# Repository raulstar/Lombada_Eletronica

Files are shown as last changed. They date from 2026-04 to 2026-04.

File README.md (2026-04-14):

#  Lombada Eletrônica - Sistema de Detecção de Velocidade com Visão Computacional

##  Descrição do Projeto
Este projeto tem como objetivo desenvolver um sistema capaz de rastrear, identificar e registrar a velocidade de veículos, além de capturar imagens, utilizando visão computacional com OpenCV em Python 3.

Na primeira versão o sistema opera em um computador embarcado, utilizando uma câmera de vídeo para monitoramento contínuo do tráfego.
Na segunda versão Usam um sensor de radar niko-ondas Para ler A velocidade.

---

##  Objetivo
Desenvolver um programa que:
- Detecte veículos em vídeo
- Rastreie cada veículo com ID único
- Calcule a velocidade com base no método VASCAR
- Registre dados e imagens dos veículos
- Identifique infrações de velocidade

---

##  Requisitos do Sistema

###  Hardware
- Gabinete metálico
– Estrutura metalica
- Banco de bateria
- A placa solar
- Mini PC x64
- Mínimo:
  - 4 GB RAM
  - Processador Intel Celeron N4120
- Compatível com:
  - Windows 10 / Windows 11 (23H2)
  - (Opcional) Raspberry Pi OS (Debian)
  - Câmera de CFTV

---

### Software
- Python 3
- OpenCV
- Adu

---

## Arquitetura de Referência
Protótipo base:
https://github.com/raulstar/Software_Lombada

---

## Funcionalidades

### Entrada de Vídeo
- Captura via:
  - Arquivo de vídeo
  - Câmera embarcada
- Suporte a resoluções:
  - 1280x720
  - 1920x1080
- FPS configurável ou automático

---

### Detecção e Rastreamento
- Identificação de veículos em diferentes:
  - Ângulos
  - Elevações
  - Sentidos de tráfego
- Atribuição de ID único por veículo
- Caixa de detecção (bounding box)
- Região de interesse (ROI) configurável

---

### Cálculo de Velocidade
- Baseado no método VASCAR
- Linhas de início/fim configuráveis
- Exibição em tempo real:
  - ID
  - Velocidade

---

### Controle de Velocidade
- Definição de limite de velocidade
- Identificação de veículos infratores

---

### 🧾 Registro de Dados (LOG)

ID   VELOCIDADE   DATA/HORA
--------------------------------------------------
1    20.66 KM/h   2025-01-21 09:16:21  <--- excedeu limite
4    29.94 KM/h   2025-01-21 09:16:26  <--- excedeu limite
7    35.99 KM/h   2025-01-21 09:16:55  <--- excedeu limite

---

###  Captura de Imagens
- Registro automático de veículos infratores
- Foco na placa
- Imagens com qualidade suficiente para OCR futuro

---

### Comunicação Serial
- Detecção automática de portas seriais
- Envio de dados via:

serial.Serial("COMX", 9600, timeout=0.5)

- Formato ASCII com velocidade excedida

---

### Dependências
Deve incluir:
- Lista completa de bibliotecas
- Versões utilizadas
- Código-fonte completo

---

## Testes Realizados
- Resoluções testadas:
  - 1280x720
  - 1920x1080

---

##  Limitações do Protótipo Atual
- Baixa precisão na detecção
- Identificação incorreta de partes de veículos
- Velocidades inconsistentes
- Perda de veículos reais
- Múltiplos registros para o mesmo veículo

---

##  Problemas Observados
- Captura de objetos errados (ex: vidro do carro)
- Falha em detectar veículos grandes (ex: caminhões)
- Poucas imagens com foco correto na placa
- Associação incorreta entre ID e imagem

---

##  Requisitos Esperados
- Um único registro por veículo
- Associação correta entre:
  - ID
  - Imagem
  - Velocidade
- Geração de miniatura por registro com uma ID

---

##  Futuras Etapas
- Migração para nuvem
- Interface web (browser)
- Controle de acesso
- Suporte a múltiplas câmeras
- Integração com OCR (leitura de placas)
- Registro e consulta de todos os dados capturados
- O uso do Radar de microondas

---

##  Protótipo
O protótipo atual já implementa grande parte das funcionalidades, porém ainda com limitações de precisão:

https://github.com/raulstar/Software_Lombada

---

##  Imagens

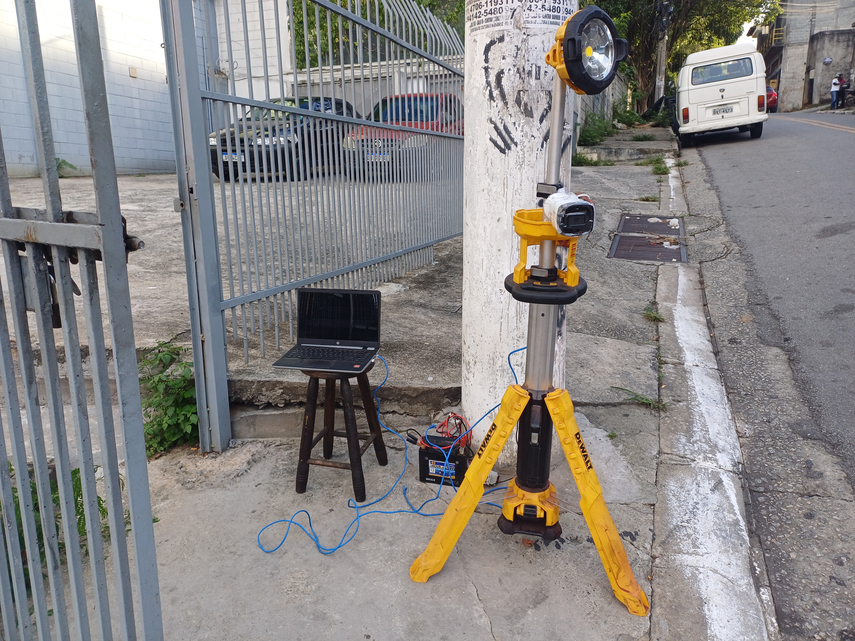
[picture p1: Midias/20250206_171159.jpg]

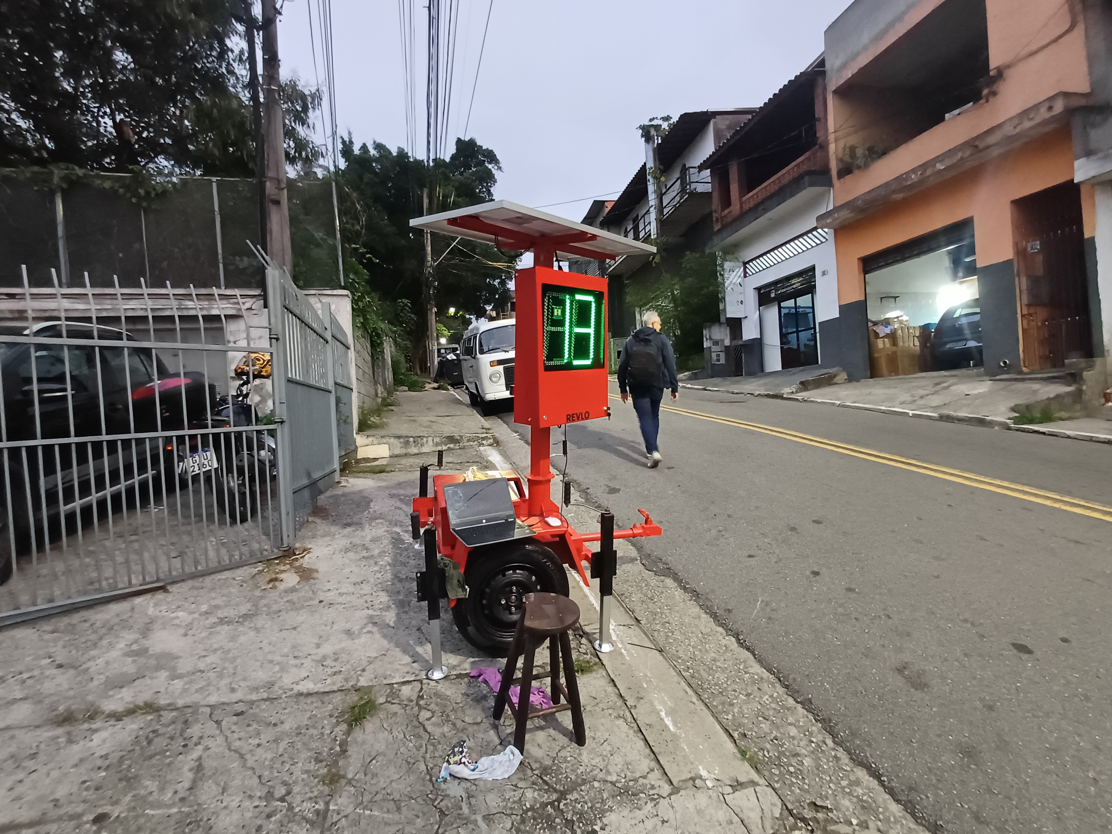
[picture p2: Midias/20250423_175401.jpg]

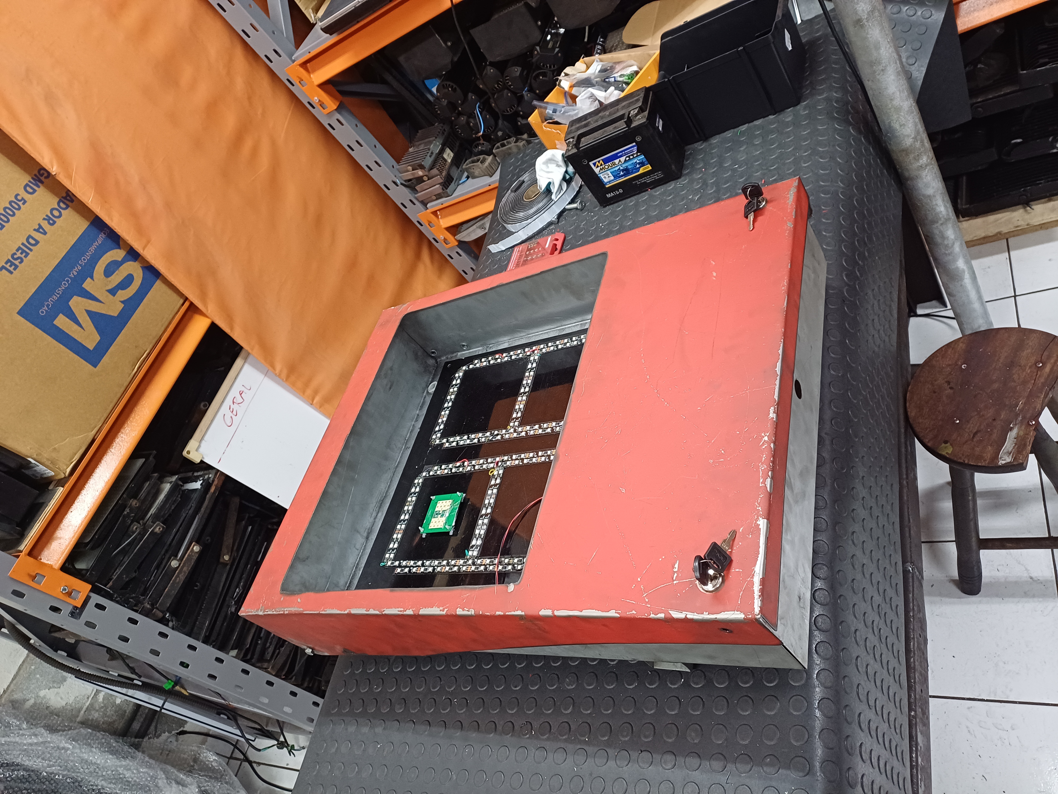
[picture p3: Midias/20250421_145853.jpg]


---

##  Vídeos

[Video 1](Midias/20250423_180011.mp4)
[Video 2](Midias/Primeiro teste (2).mp4)

---

##  Observação Final
Apesar das limitações, o protótipo demonstrou viabilidade ao:
- Detectar veículos corretamente em diversos cenários
- Capturar imagens com enquadramento adequado da placa
O pretóxico Radar Foi usado diversas vezes inclusive um dado para clientes Mas o projeto está alto pausado no Momento.
O próximo passo ser A captura das irmãs com a Câmera e o enviou para um servidor via MQTT.

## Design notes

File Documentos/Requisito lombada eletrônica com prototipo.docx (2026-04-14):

Requisitos do Projeto: Lombada Eletrônica

Objetivo:
Desenvolver um programa que rastreie, identifique e registre a velocidade e imagens de veículos utilizando uma câmera de vídeo, operando em um computador embarcado.

Primeira Etapa

Desenvolvimento de um programa em Python 3, baseado na biblioteca OpenCV, que deve rodar em:

Mini PC x64 com as seguintes especificações mínimas de 4 GB de RAM, Processador Celeron N4120, Compatível com Windows 10 ou Windows 11 23H2. Opcionalmente: Suporte ao sistema operacional Raspberry Pi OS (Debian).

Referência de arquitetura:
O protótipo pode seguir como base o exemplo disponível em:
https://github.com/raulstar/Software_Lombada

Requisitos do Programa:

- O cálculo da velocidade deve ser baseado no conceito VASCAR (saiba mais (https://en.wikipedia.org/wiki/VASCAR)).
- Deve permitir a definição da velocidade máxima por interface ou variável.
- O programa deve oferecer suporte à captura de vídeo por arquivo ou câmera embarcada.
- É necessário processar vídeos em resoluções de 1280 x 720 e 1920 x 1080, ajustáveis por variável ou detectadas automaticamente.
- Deve suportar diferentes taxas de quadros, configuráveis por variável ou por detecção automática.
- O sistema deve rastrear e registrar veículos em diferentes ângulos, elevações, sentidos de tráfego e configurações de câmeras
- Deve permitir a definição de uma região de interesse (ROI), opcionalmente ajustável por variáveis. configuráveis por variável ou por detecção automática
- Ter como opcional o desenho de linhas de início e fim para detecção de velocidade e o desenho de uma caixa ao redor dos objetos rastreados. Cada objeto deve receber um ID único.
- O programa deve estimar a velocidade dos veículos, exibindo o ID e a velocidade junto à caixa de rastreamento.
- Deve ser possível registrar os dados em um arquivo de log, incluindo a quantidade total de veículos detectados, a velocidade de cada veículo e a identificação daqueles que ultrapassaram o limite de velocidade. Além disso, o sistema deve capturar imagens dos veículos que excederem o limite, com foco na placa.
- O programa deve realizar a varredura e identificação das portas seriais disponíveis no dispositivo, enviando a velocidade excedida no formato string ASCII para a porta serial disponível no seguinte formato: serial.Serial("COMX", 9600, timeout=0.5).
- É necessário fornecer a relação completa das bibliotecas, dependências e versões utilizadas no programa, bem como incluir todo o código-fonte no projeto.

Exemplo de Testes

Exemplo testes realizados com um programa protótipo. Resoluções testadas: 1280 x 720 e 1920 x 1080.

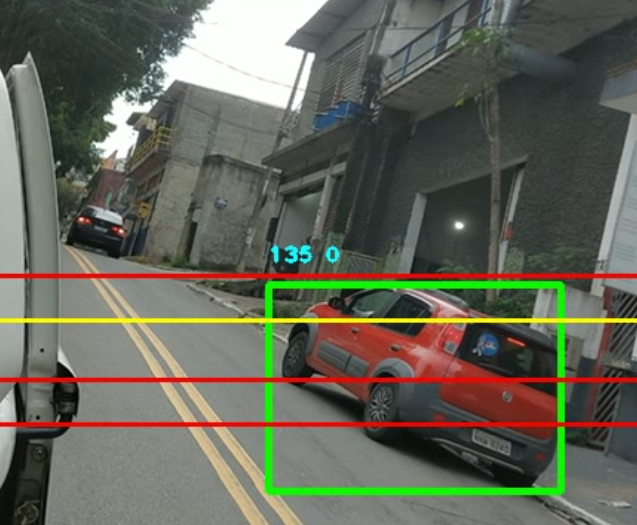
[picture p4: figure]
Teste do prototipo
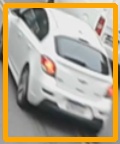
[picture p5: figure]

O As imagens capturadas e registradas deve garantir legibilidade suficiente nas imagens capturadas para integração futura com um programa de OCR.

Futuras Etapas

Com base nos resultados desta primeira etapa, a próxima fase incluirá a migração do programa para a nuvem, com interface acessível via navegador, gerenciamento de acesso, ajuste das variáveis, suporte a diversas câmeras, reconhecimento óptico das placas, registro e consulta de todos os dados capturados.

Protótipo

Foi feito um protótipo para testar a viabilidade do projeto já com a maior parte das funcionalidades funcionais embora a precisão ainda é muito baixa e detecta erroneamente os veículos atribuindo velocidades inconsistentes esse projeto está disponível em: https://github.com/raulstar/Software_Lombada

O exemplo abaixo foi capturado com uma Câmera HD com resolução de 1920 x 1080 em uma rua em frente à nossa sede nesse exemplo tem 3 veículos, mas esse protótipo capturou Falsamente o vidro de um carro e ignorou a frente do caminhão.

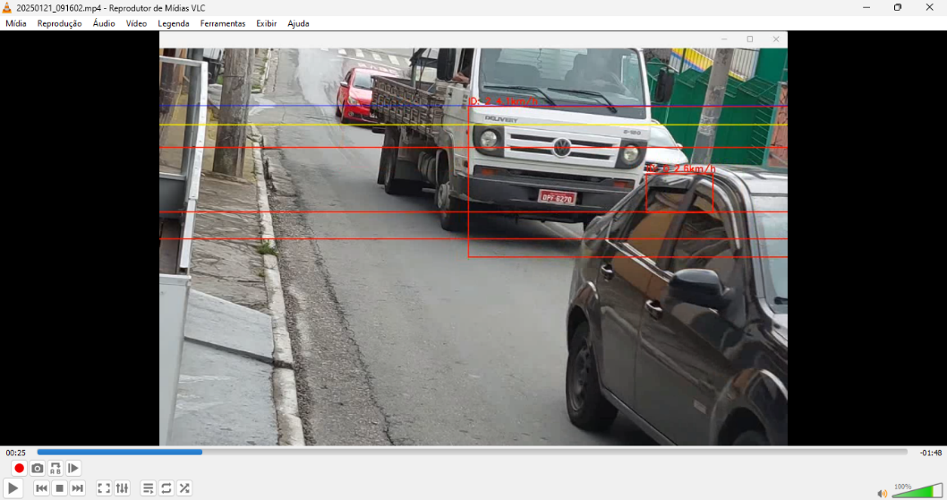
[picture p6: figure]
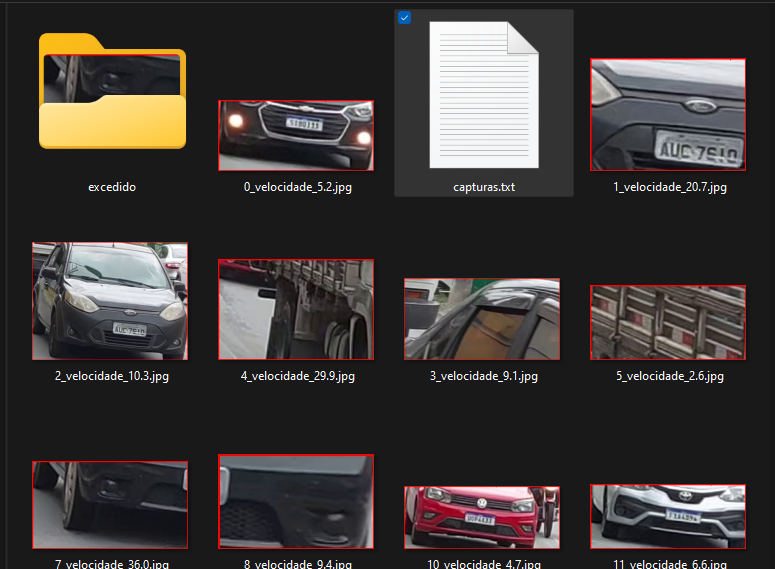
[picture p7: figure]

O protótipo também salva as imagens capturadas do veículo nesse vídeo, com 6 veículos passando foro capturado apenas 3 veículos diferentes sendo que pouca dessas imagens foro capturada apenas à frente com a placa.

Apesar do protótipo conseguir capturar a maioria dos veículos também captura parte, atribuindo uma ideia e uma velocidade errônea ao mesmo veículo.

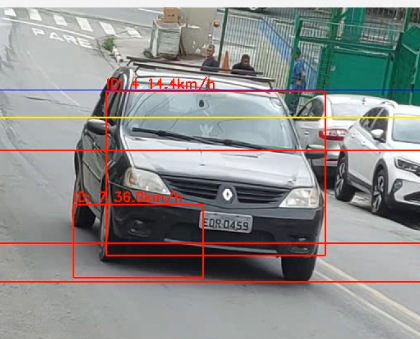
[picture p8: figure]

O protótipo também já faz o registro dos veículos capturados em um LOG com o ID atribuído seguido do dia e horário nesse caso foi detectado apenas 3 veículos e registrado, a ID Registrada está associada a imagem de parte de um veículo e não da foto com.

ID VELOCIDADE DATA/HORA

1 20.66 KM/h 2025-01-21 09:16:21 <---excedeu limite

4 29.94 KM/h 2025-01-21 09:16:26 <---excedeu limite

7 35.99 KM/h 2025-01-21 09:16:55 <---excedeu limite

O projeto deve fazer um único registro para cada veículo detectado marcar os que se deu o limite e criar uma miniatura associado ao registro com uma ID

Por outro lado o protótipo foi capaz de capturar vários veículos centralizando exatamente a placa para posteriormente ser reconhecida por um segundo programa de OCR

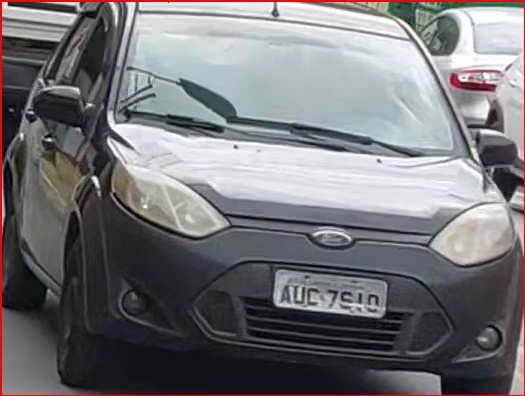
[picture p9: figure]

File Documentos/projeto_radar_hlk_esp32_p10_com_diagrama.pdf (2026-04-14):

## Projeto: Radar HLK-LD306S com Painel LED P10 e ESP32

Este projeto visa exibir a velocidade captada pelo módulo de radar Hi-Link 24G HLK-LD306S em um painel LED P10, utilizando uma ESP32 para o controle e comunicação. O sistema suporta múltiplas placas LED em matriz (ex.: 2x2 painéis),
permitindo uma visualização ampla e de alta visibilidade.

Objetivos:
- Captar a velocidade do radar e exibi-la em tempo real em um painel de LED P10.
- Possibilitar escalabilidade com múltiplos painéis (2x2 ou mais).
- Utilizar uma solução simples, prática e eficiente com ESP32.

Componentes principais:
- Módulo de Radar Hi-Link HLK-LD306S
- Microcontrolador ESP32 (Dev Kit V1)
- Painéis LED P10 (HUB75)
- Fonte de alimentação 5V 40A

Diagrama de Conexão:

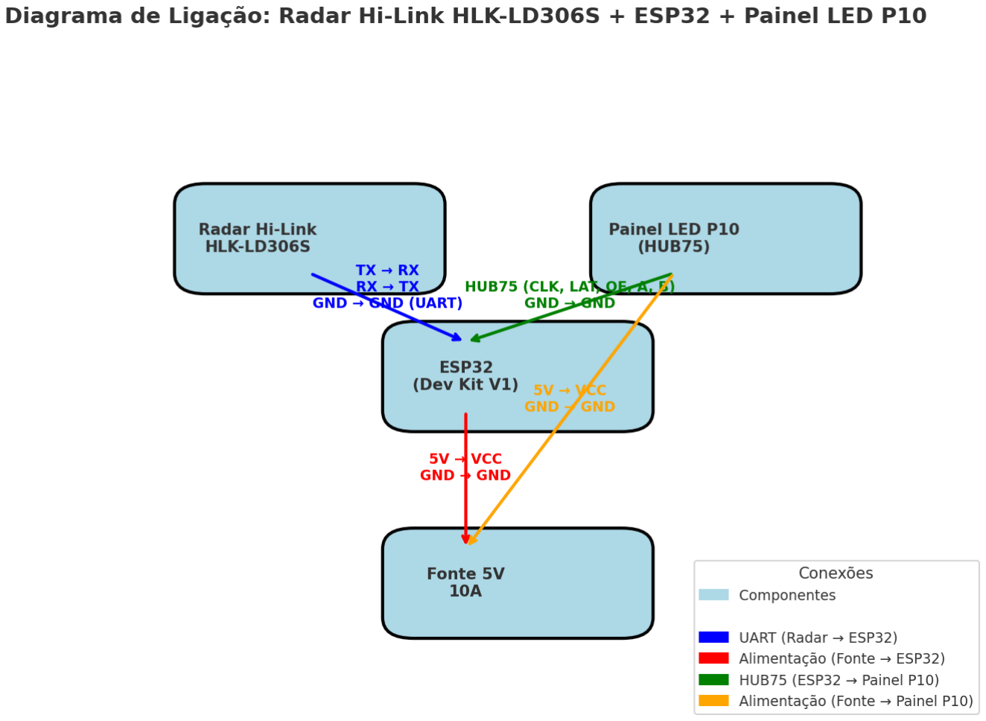
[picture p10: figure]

Código (Arduino IDE):

#include <PxMatrix.h>

#include <HardwareSerial.h>

// Configurações de pinos ESP32 para HUB75 #define P_A 12
#define P_B 13

#define P_C 14

#define P_D 27

#define P_LAT 26

#define P_OE 25

#define P_CLK 16

// Configuração da matriz P10 (quantidade de módulos) #define PANELS_WIDTH 2 // Número de painéis na largura #define PANELS_HEIGHT 2 // Número de painéis na altura

// Inicializa a matriz LED PxMatrix
PxMATRIX display(32 * PANELS_WIDTH, 16 * PANELS_HEIGHT, P_LAT, P_OE, P_A, P_B, P_C, P_D, P_CLK);

// Configura comunicação serial com o radar
HardwareSerial RadarSerial(1);
int velocidade = 0;

void setup() {
Serial.begin(115200);
RadarSerial.begin(9600, SERIAL_8N1, 17, 16); // TX=17, RX=16 (ajuste conforme necessário)

// Inicializa display P10
display.begin(16);
display.setFastUpdate(true); display.clearDisplay();
}

void loop() {
// Lê dados do radar (esperando velocidade em formato simples, ex: '85') if (RadarSerial.available()) {
String data = RadarSerial.readStringUntil('\n');
velocidade = data.toInt();
}

// Exibe a velocidade no painel display.clearDisplay();
display.setCursor(5, 10);
display.setTextSize(3);
display.print(velocidade); display.print(" km/h");
display.showBuffer();

delay(200);
}
Conclusão:

Este projeto oferece uma solução prática e eficiente para exibir velocidades captadas pelo radar Hi-Link HLK-LD306S em
um painel LED P10 de múltiplas placas. Com o uso da ESP32 e da biblioteca PxMatrix, o sistema se mantém simples, eficiente e escalável, adequado para uso em lombadas eletrônicas, radares móveis ou sinalizações em tempo real.

Para futuras expansões:
- Adicionar limites de velocidade com alertas visuais (LED piscando em vermelho).
- Implementar conectividade via Wi-Fi para envio de dados a um servidor.
- Integrar botões físicos ou aplicativos para configuração remota.

Projeto pronto para ser implementado e escalado conforme a necessidade do cliente.

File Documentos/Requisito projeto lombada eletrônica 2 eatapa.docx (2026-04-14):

Requisitos do Projeto: Lombada Eletrônica 2 etapa

Segunda etapa

De Uma vez validado a primeira etapa as funcionalidades abaixo devem ser acrescentadas.

- Cada veículo detectado deve receber um ID único que pode ser baseada na data e hora.
- A ID e a velocidade junto à caixa de rastreamento.
- O sistema deve capturar imagens dos veículos com foco na placa, nomear a imagem com o ID e velocidade, e se esta foi excedida.
- Registrar os dados em um arquivo de log, em um diretório local nomeado com a data, incluindo a ID, hora, velocidade, se excedido ou não, quantidade total de veículos detectados..
- O programa deve ter um módulo que busca e identificação as portas seriais disponíveis no dispositivo, e se alguma conectada, envia a velocidade excedida no formato string ASCII para a porta serial disponível no seguinte formato: serial.Serial("COMX", 9600, timeout=0.5). Essa comunicação para teste pode ser feita em um terminal rodando na própria máquina.

Terceira etapa

Identificação das placas e organização do LOG de registro.

Desenvolver ou selecionar uma aplicação independente da primeira, pode ser uma aplicação comercial adaptada.

- Detectar as imagens conforme são salvas em um diretório feitas pela aplicação anterior.
- Reconhecer os caracteres da placa na imagem.
- Em um segundo diretório, salvar esta imagem acrescentando os caracteres da placa no título da imagem.
- Localizar através da ID, o registro relativo a imagem salva anteriormente no log, acrescentar a identificação da placa a este log (pode ser no formato CSV).
- Ser disponível, abrir uma conexão com um servidor e enviar a ID com as informações para o servidor ou atualizar um log remoto. Pode ser no formato de string ou Jason.

Futuras Etapas

Com base nos resultados desta primeira etapa, a próxima fase incluirá a migração do programa para a nuvem, com interface acessível via navegador, gerenciamento de acesso, ajuste das variáveis, suporte a diversas câmeras, reconhecimento óptico das placas, registro e consulta de todos os dados capturados.

Revlo - Torres de Iluminação

Endereço (https://www.google.com/search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): Av. Calil Mohamad Rahal, 730 - Vila Sao Silvestre, Barueri - SP, 06417-010

CNPJ 51.710.608/0001-40

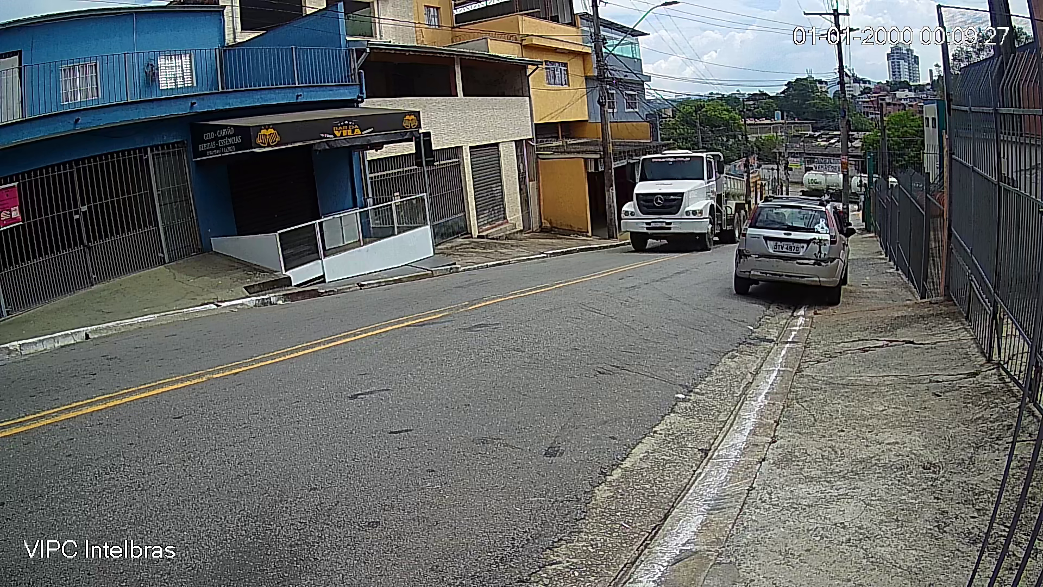
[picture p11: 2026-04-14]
Software/Software Lombada Radar/28 - 30Km .png

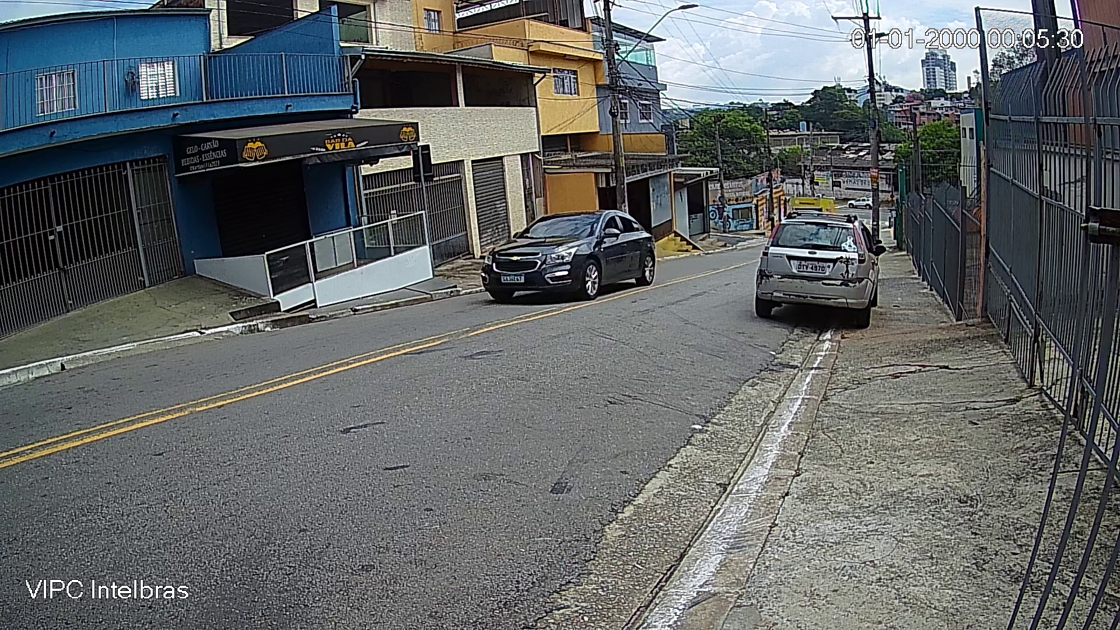
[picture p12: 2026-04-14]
Software/Software Lombada Radar/11 - 19Km .png

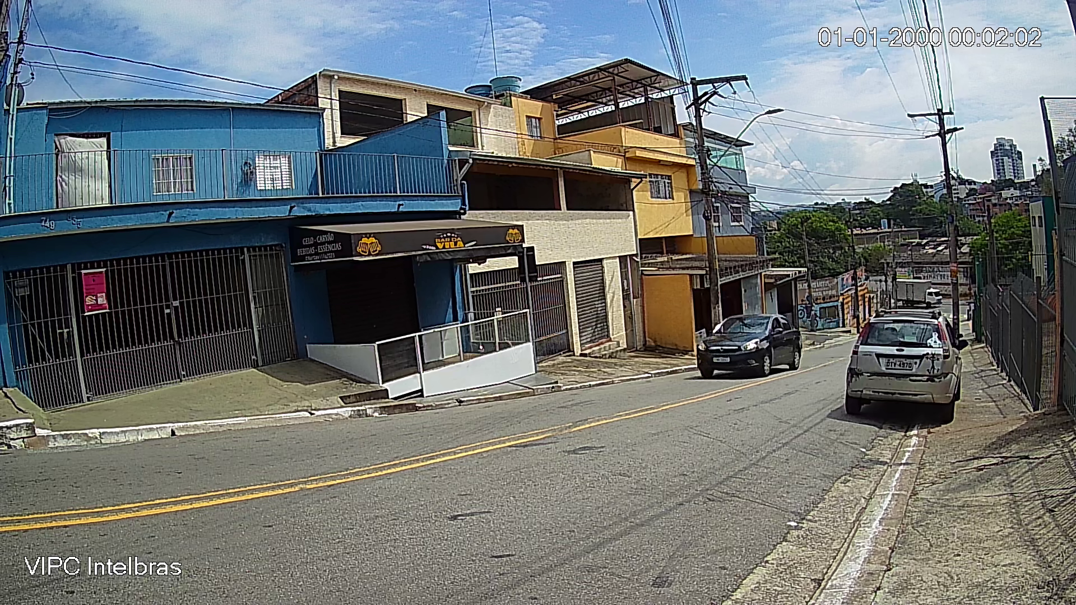
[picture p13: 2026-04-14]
Software/Software Lombada Radar/Velocidade 29Km 2.png

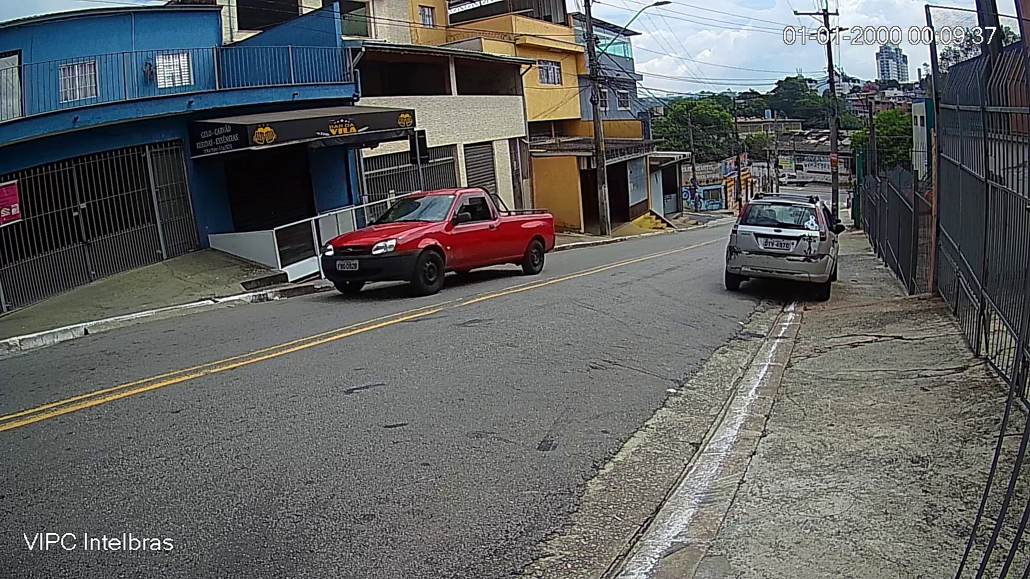
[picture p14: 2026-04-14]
Software/Software Lombada Radar/31 - 10Km .png

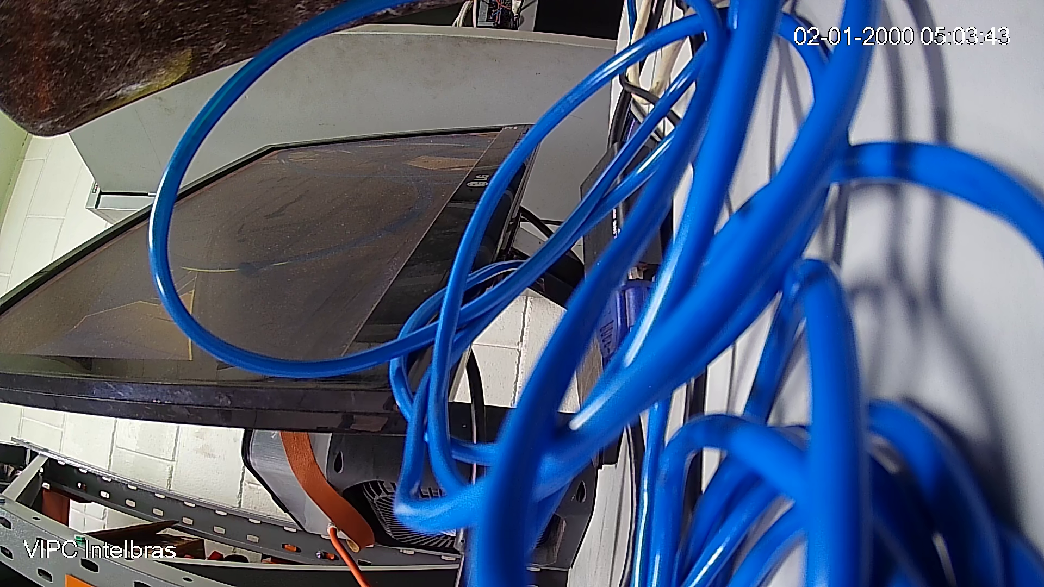
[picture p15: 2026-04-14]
Software/Software Lombada Radar/4 - 12Km .png

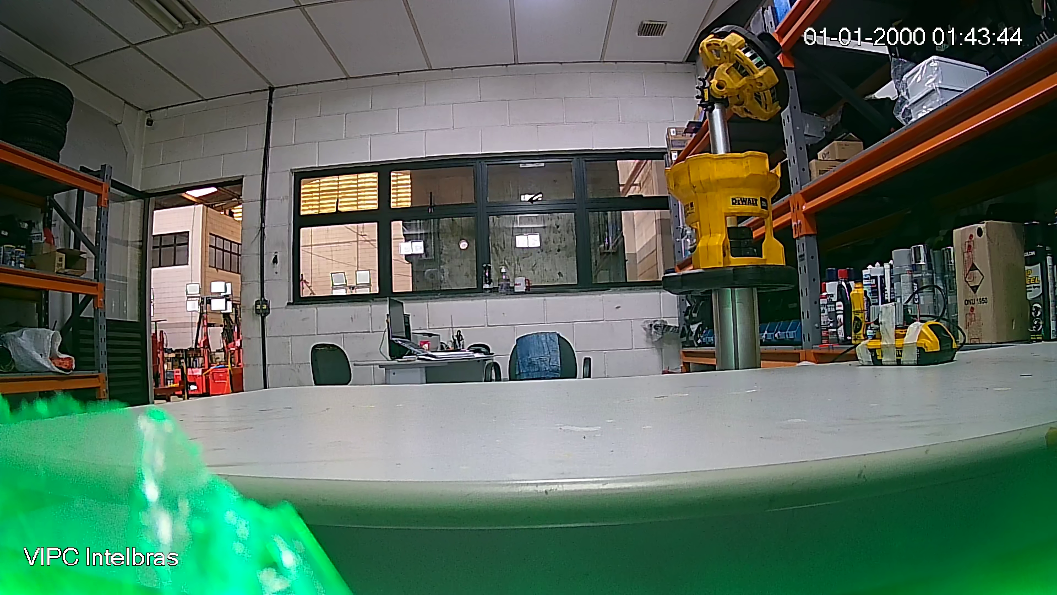
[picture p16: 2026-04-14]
Software/Software Lombada Radar/5 - 9Km .png

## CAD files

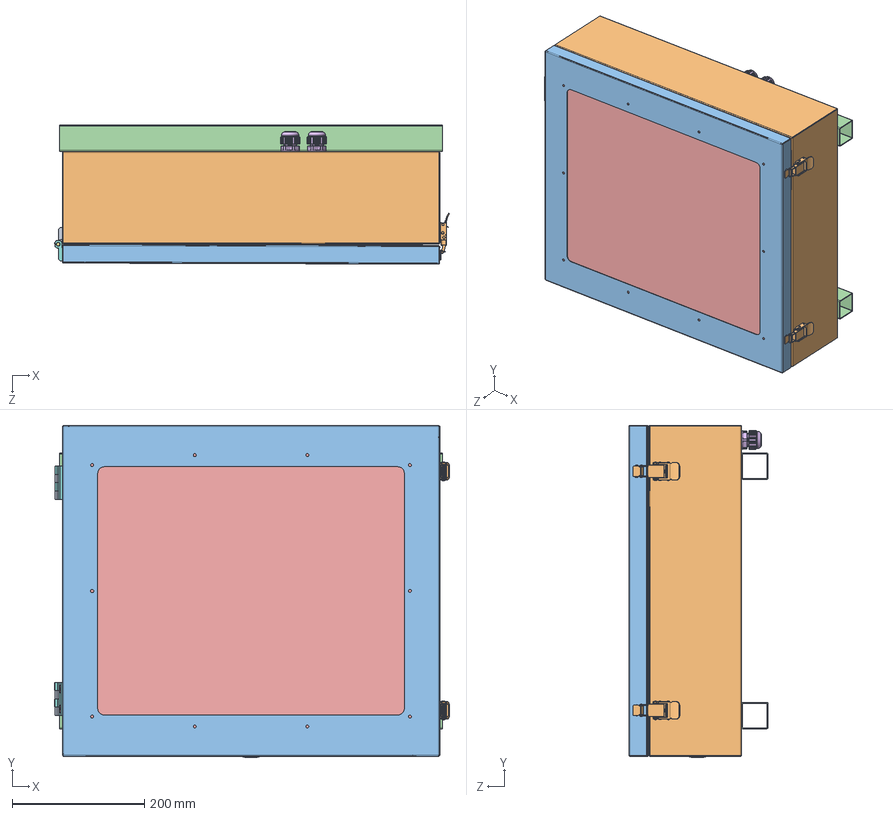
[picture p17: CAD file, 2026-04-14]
Hardware/Gabinete Lombada Eletronica V3/Gabinete Lombada Eletronica.SLDASM
596.7 x 502.0 x 210.3 mm
Display LED 7 Zhengzhou V3
Fundo
Tampa
Tubo Suporte x 3
Policarbonato 500 x 500 x 3mm
Prensa cabo PG11 1_2 x 2
Controlador De Carga Solar 30a 12_24v PWM
Tampão para Furo 22mm ^Gabinete painel LED
Porta Fusível Cartucho RT18-32 10x38mm
TRILHO DIN 100
BATERIA 12V 33AH
ALÇA BATERIA
PARAFUSO CB. CHATA SEXT. INT. M6 X 12 DIN 7991 INOX x 8
PORCA SEXT. AUTOTRAVANTE M6 DIN 985 TRIV. BRANCO x 8
Pino CFM.50-AE-V0-SH-6-3 x 2
lado CFM.50-AE-V0-SH-6-1 x 2
lado CFM.50-AE-V0-SH-6-2 x 2
Fecho Santo Angelo Engate Rápido Case Ra3 P x 2
REBITE POP INOX SSD 64-SS Ø4,8 X 10,8 MM x 2
Fita espuma Polietileno 20 x 4^Gabinete Lombada Eletronica
Espaçador x 10

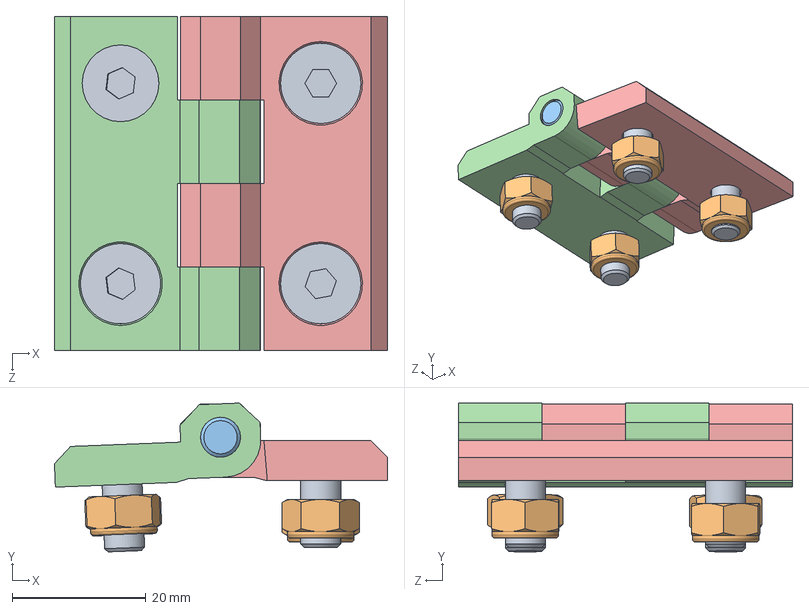
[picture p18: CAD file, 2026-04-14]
Hardware/Gabinete Lombada Eletronica V3/Desenho/Dobradiça 50x50 Em Zamak/SOLIDWORKS/Hinges CFM_50-AE-V0-SH-6 (0).sldasm
49.9 x 22.3 x 50.0 mm
PARAFUSO CB. CHATA SEXT. INT. M6 X 12 DIN 7991 INOX x 4
PORCA SEXT. AUTOTRAVANTE M6 DIN 985 TRIV. BRANCO x 4
Hinges CFM.50-AE-V0-SH-6-3
Hinges CFM.50-AE-V0-SH-6-1
Hinges CFM.50-AE-V0-SH-6-2

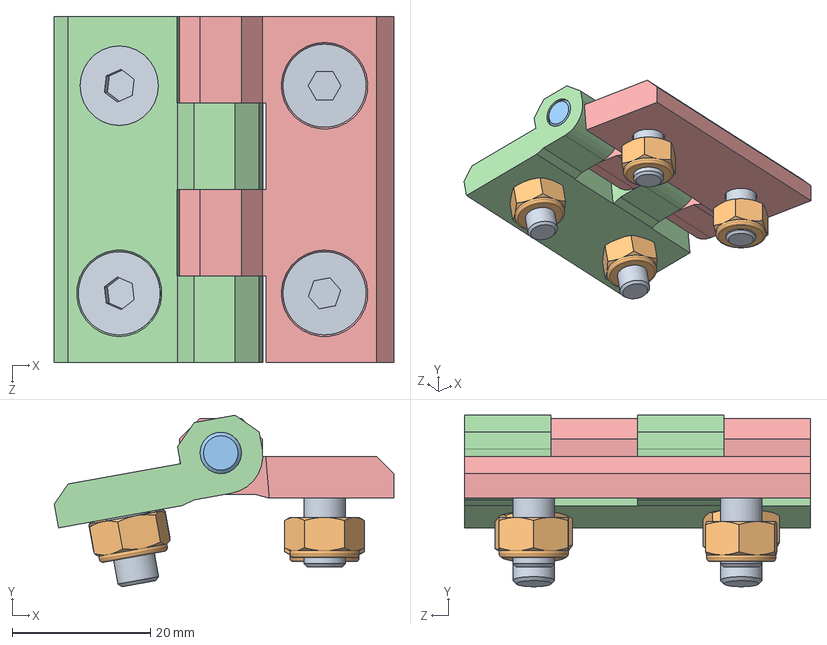
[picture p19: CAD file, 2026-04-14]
Hardware/Gabinete Lombada Eletronica V3/Desenho/Dobradiça Zamac 50 X 50.SLDASM
49.1 x 24.8 x 50.0 mm
PARAFUSO CB. CHATA SEXT. INT. M6 X 12 DIN 7991 INOX x 4
PORCA SEXT. AUTOTRAVANTE M6 DIN 985 TRIV. BRANCO x 4
Pino CFM.50-AE-V0-SH-6-3
lado CFM.50-AE-V0-SH-6-1
lado CFM.50-AE-V0-SH-6-2

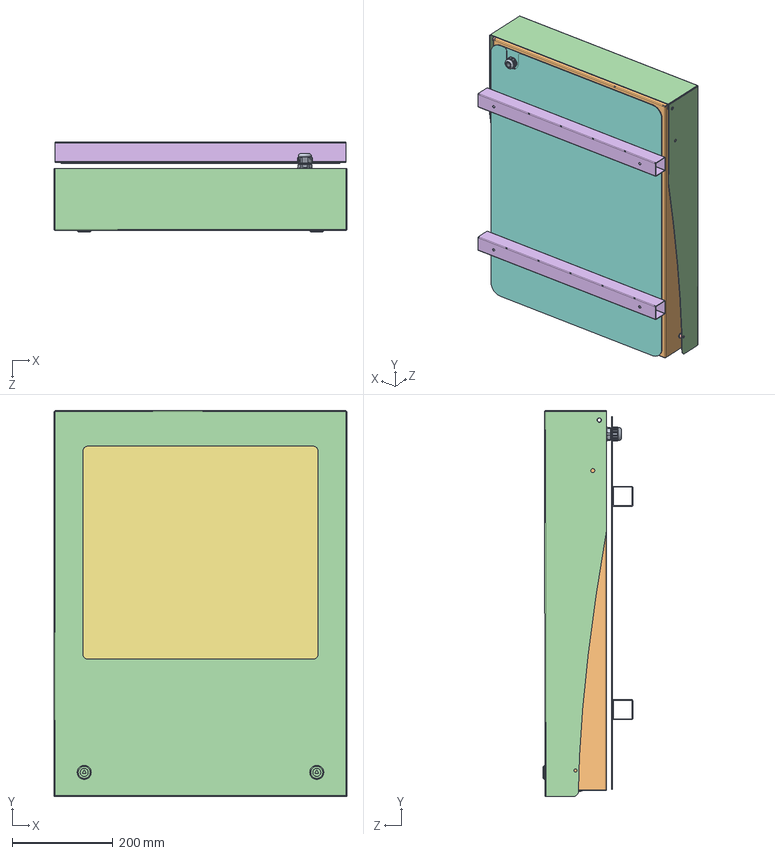
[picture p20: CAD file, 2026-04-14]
Hardware/Gabinete Lombada Eletronica/Gabinete Lombada Eletronica.SLDASM
582.5 x 767.8 x 178.2 mm
Display^Gabinete Lombada Eletronica
Fundo
Display LED 7 segmentos
Tampa
REBITE ROSCADO CIL. CAB. PLANA M8 ZINCADO RK PLUS 8PO300 x 4
Tubo Suporte x 2
Policarbonato^Gabinete Lombada Eletronica
Prensa cabo 1_2
Bateria 12v 18Ah
Solar Charger Controller
Fecho Lingueta Triangulo Reta x 2
Tampão para Furo 22mm ^Gabinete painel LED
Porta Fusível Cartucho RT18-32 10x38mm .step
8961K85_Steel DIN 3 Rail.step

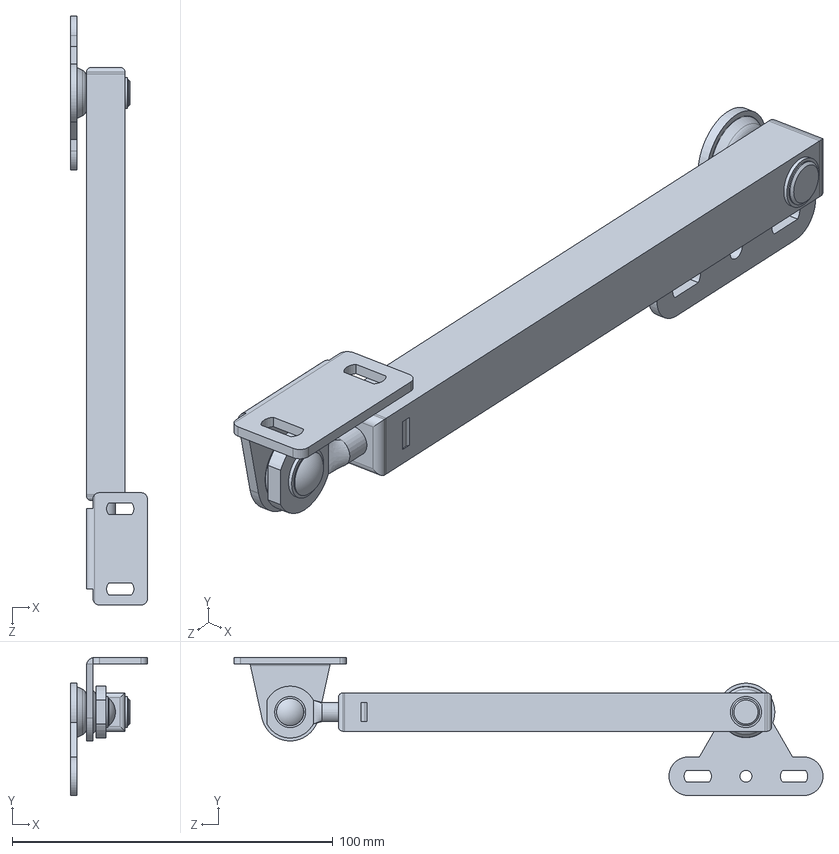
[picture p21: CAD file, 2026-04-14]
Hardware/Gabinete Lombada Eletronica V3/Desenho/MOLA A GAS 80N.SLDPRT
24.0 x 43.0 x 183.5 mm

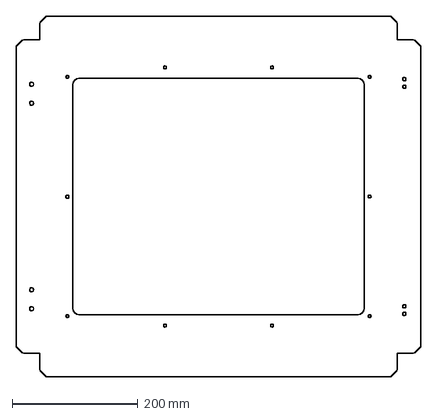
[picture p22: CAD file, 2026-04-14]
Hardware/Gabinete Lombada Eletronica V3/DXF/TAMPA V3.DXF
641.9 x 571.9 mm

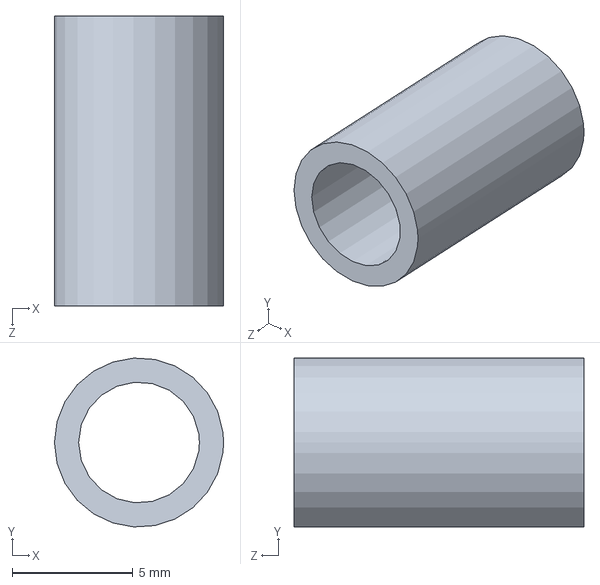
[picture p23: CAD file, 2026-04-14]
Hardware/Gabinete Lombada Eletronica V3/Espaçador.SLDPRT
7.00 x 6.99 x 12.0 mm

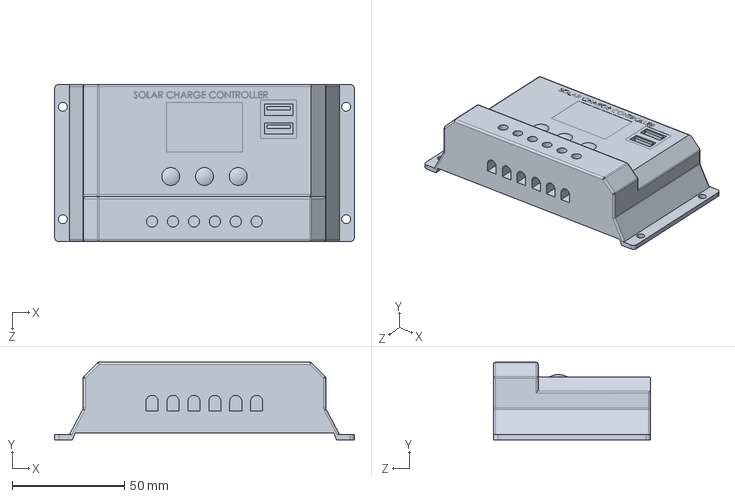
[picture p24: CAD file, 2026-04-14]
Hardware/Gabinete Lombada Eletronica/Solar Charger Controller.SLDPRT
133.4 x 34.5 x 70.0 mm

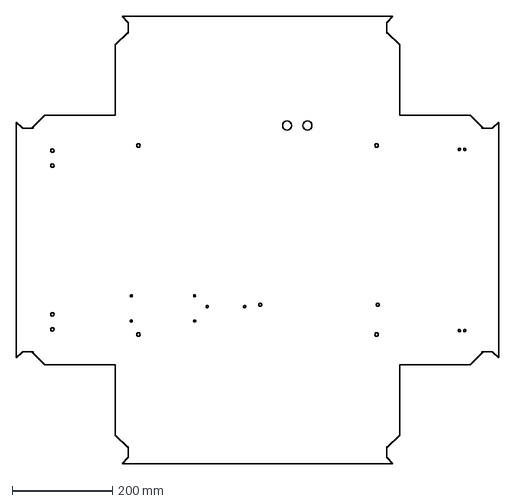
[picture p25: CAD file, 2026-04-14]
Hardware/Gabinete Lombada Eletronica V3/DXF/FUNDO V3.DXF
961.6 x 891.6 mm

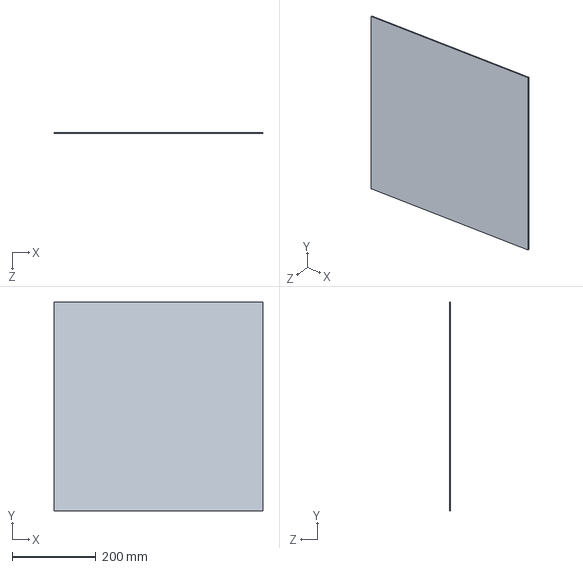
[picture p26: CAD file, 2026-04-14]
Hardware/Gabinete Lombada Eletronica V3/Policarbonato 500 x 500 x 3mm.SLDPRT
500.0 x 500.0 x 3.00 mm

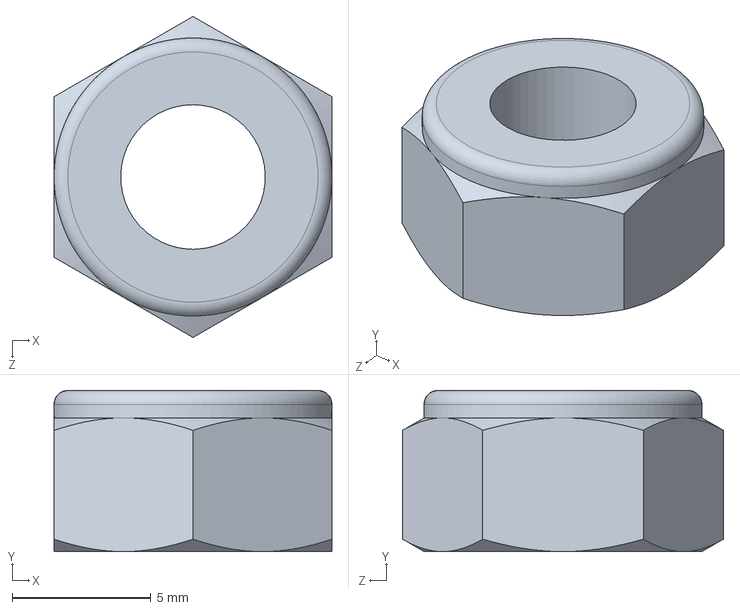
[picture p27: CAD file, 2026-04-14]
Hardware/Gabinete Lombada Eletronica V3/Desenho/PORCA SEXT. AUTOTRAVANTE M6 DIN 985 TRIV. BRANCO.SLDPRT
10.0 x 5.80 x 11.5 mm

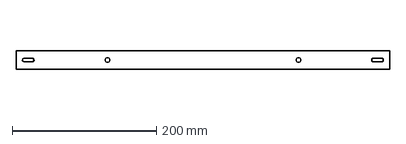
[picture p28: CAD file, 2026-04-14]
Hardware/Gabinete Lombada Eletronica V3/DXF/ALÇA V3.DXF
517.8 x 25.0 mm

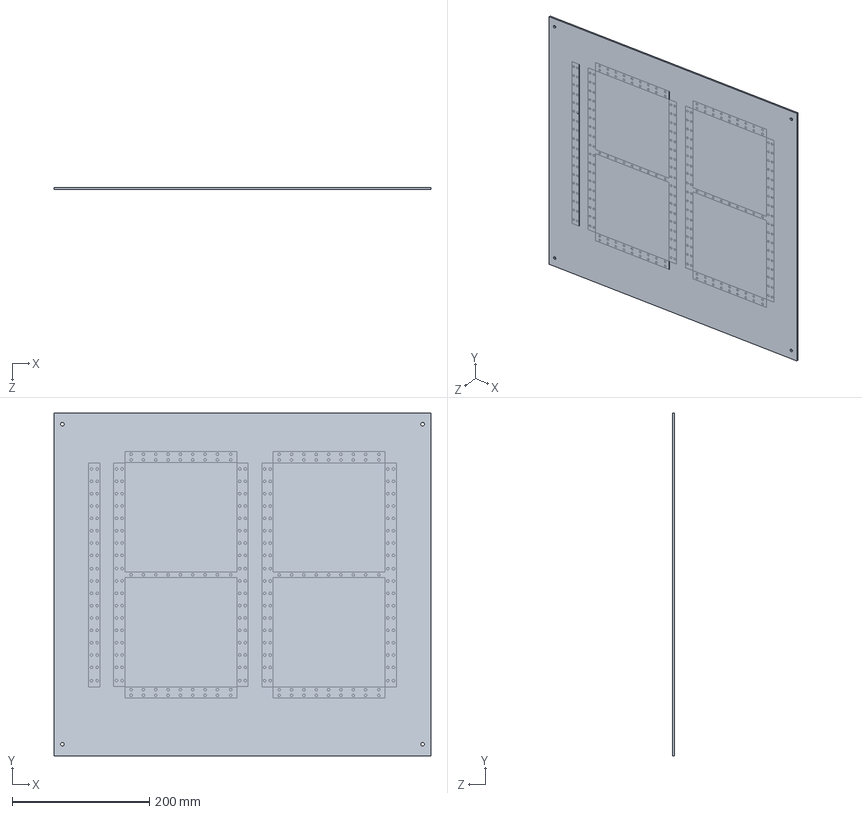
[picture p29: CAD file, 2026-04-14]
Hardware/Gabinete Lombada Eletronica/Display LED 7 segmentos.SLDPRT
550.0 x 500.0 x 3.20 mm

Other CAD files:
Hardware/Gabinete Lombada Eletronica V3/Desenho/Gabinete Lombada Eletronica.SLDASM
Hardware/Gabinete Lombada Eletronica V3/Desenho/Dobradiça 50x50 Em Zamak/SOLIDWORKS/Hinges CFM.50-AE-V0-SH-6-1.sldprt
Hardware/Gabinete Lombada Eletronica V3/Desenho/Dobradiça 50x50 Em Zamak/SOLIDWORKS/Hinges CFM.50-AE-V0-SH-6-2.sldprt
Hardware/Gabinete Lombada Eletronica V3/Desenho/Dobradiça 50x50 Em Zamak/SOLIDWORKS/Hinges CFM.50-AE-V0-SH-6-3.sldprt
Hardware/Gabinete Lombada Eletronica V1/85985K161_Locking Panel Plugs.STEP
Hardware/Gabinete Lombada Eletronica V1/8961K85_Steel DIN 3 Rail.STEP
Hardware/Gabinete Lombada Eletronica V1/ALÇA BATERIA.SLDPRT
Hardware/Gabinete Lombada Eletronica V1/Display LED 7 Zhengzhou.SLDPRT
Hardware/Gabinete Lombada Eletronica V1/Fecho Lingueta Triangulo Reta.SLDPRT
Hardware/Gabinete Lombada Eletronica V1/Fundo.SLDPRT
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

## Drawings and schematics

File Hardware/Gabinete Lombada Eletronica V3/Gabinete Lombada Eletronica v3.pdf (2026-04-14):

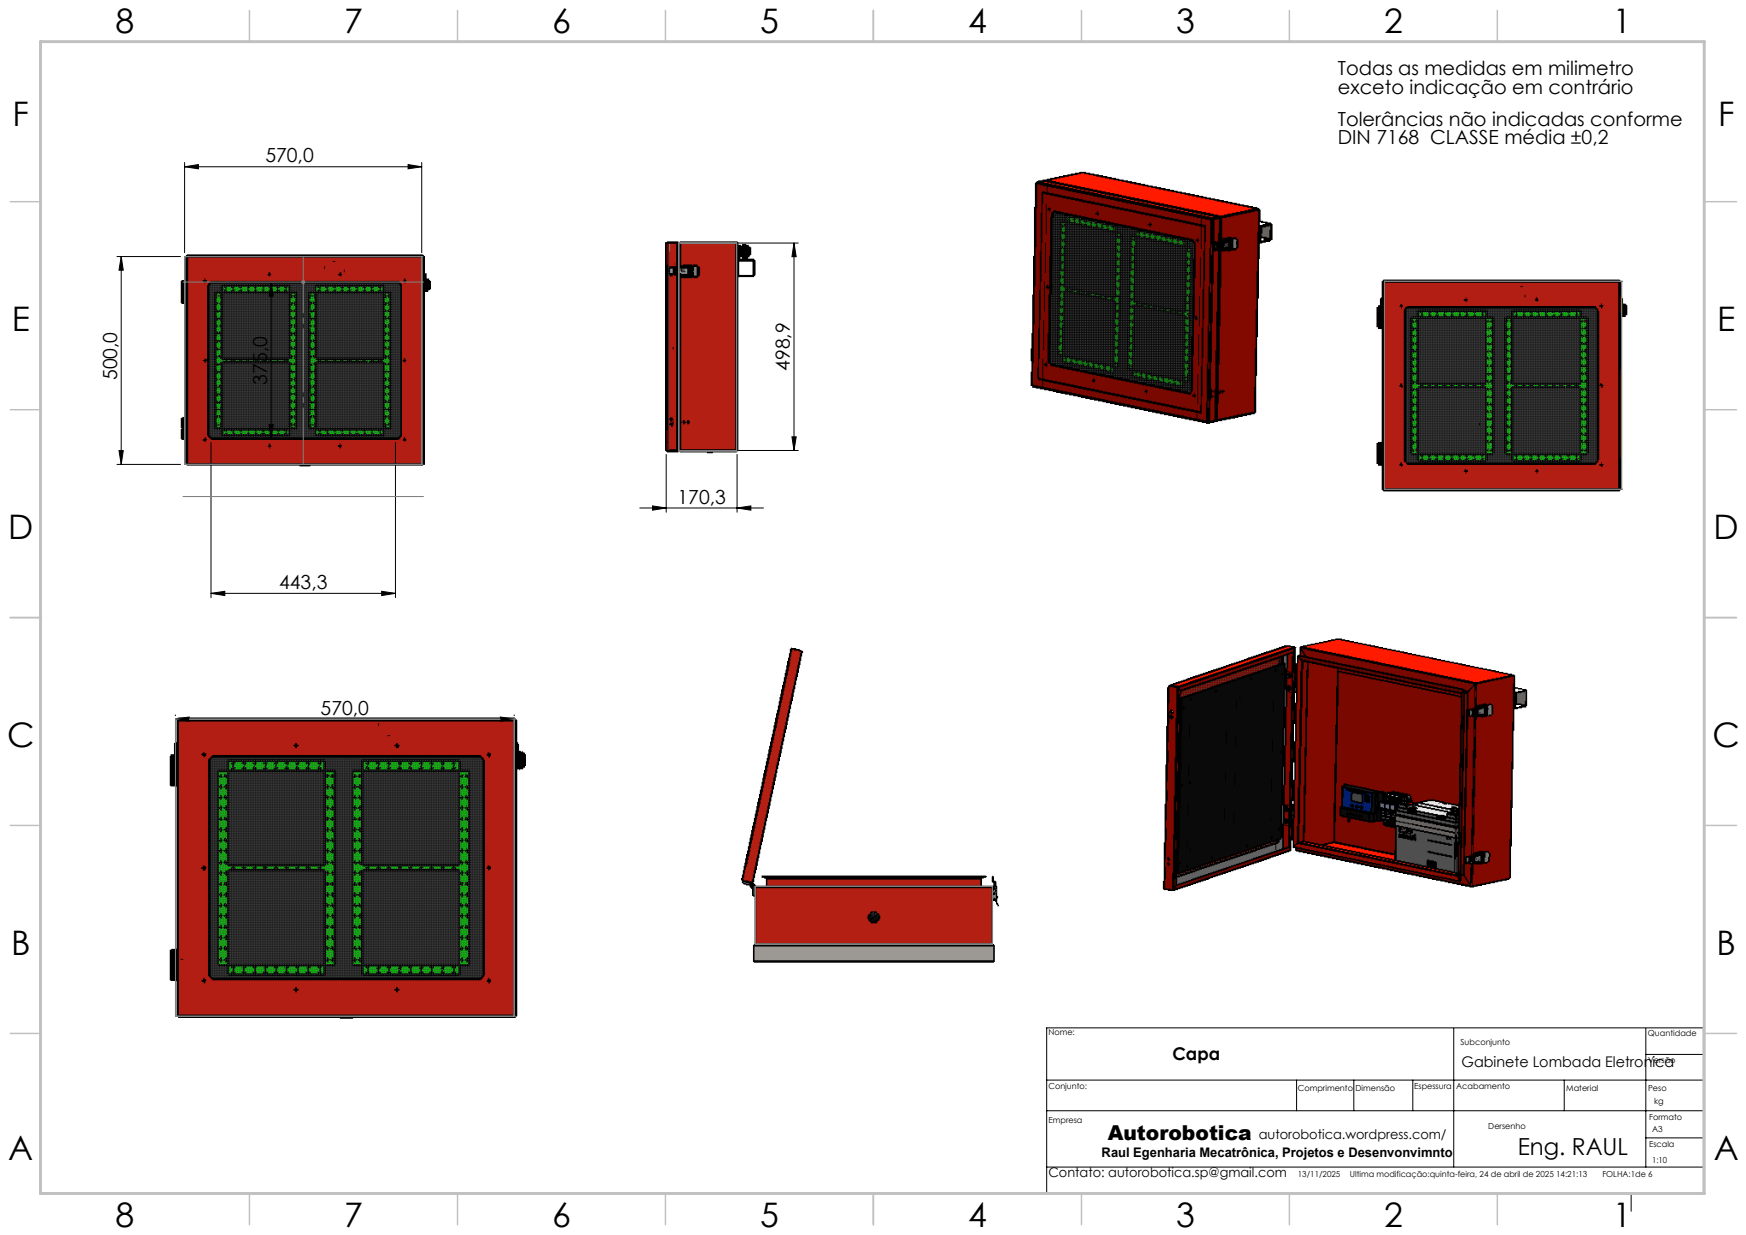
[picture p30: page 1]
Contato: autorobotica.sp@gmail.com; Ultima modificação:quinta-feira, 24 de abril de 2025 14:21:13; FOLHA:1de 6; Capa; Gabinete Lombada Eletronica

Todas as medidas em milimetro
exceto indicação em contrário
Tolerâncias não indicadas conforme
DIN 7168 CLASSE média ±0,2

Conjunto: | Comprimento | Dimensão | Espessura | Acabamento | Material | Peso kg
Empresa Autorobotica autorobotica.wordpress.com/ Raul Egenharia Mecatrônica, Projetos e Desenvonvimnto | | | | Dersenho Eng. RAUL | | Formato A3

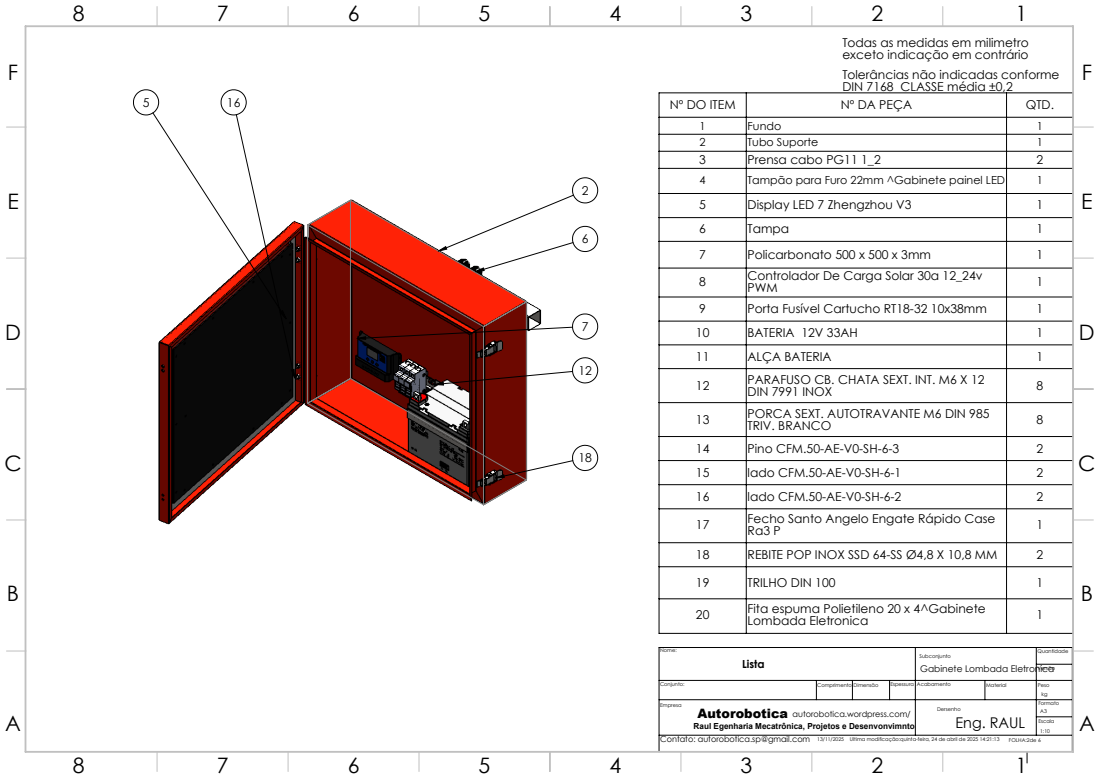
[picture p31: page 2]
Nº DO ITEM; Nº DA PEÇA; QTD. 1; Fundo; Tubo Suporte; Prensa cabo PG11 1_2; Tampão para Furo 22mm ^Gabinete painel LED; Display LED 7 Zhengzhou V3; Tampa; Policarbonato 500 x 500 x 3mm; Controlador De Carga Solar 30a 12_24v; Lista; Gabinete Lombada Eletronica

Tolerâncias não indicadas conforme
DIN 7168 CLASSE média ±0,2

PWM | 1
9 | Porta Fusível Cartucho RT18-32 10x38mm | 1
10 | BATERIA 12V 33AH | 1
11 | ALÇA BATERIA | 1
12 | PARAFUSO CB. CHATA SEXT. INT. M6 X 12 DIN 7991 INOX | 8

13 | PORCA SEXT. AUTOTRAVANTE M6 DIN 985 TRIV. BRANCO | 8

14 | Pino CFM.50-AE-V0-SH-6-3 | 2
15 | lado CFM.50-AE-V0-SH-6-1 | 2
16 | lado CFM.50-AE-V0-SH-6-2 | 2
17 | Fecho Santo Angelo Engate Rápido Case Ra3 P | 1

18 | REBITE POP INOX SSD 64-SS Ø4,8 X 10,8 MM | 2
19 | TRILHO DIN 100 | 1
20 | Fita espuma Polietileno 20 x 4^Gabinete Lombada Eletronica | 1

Conjunto: | Comprimento | Dimensão | Espessura | Acabamento | Material | Peso kg

Empresa Autorobotica autorobotica.wordpress.com/ | | | | Dersenho | | Formato A3

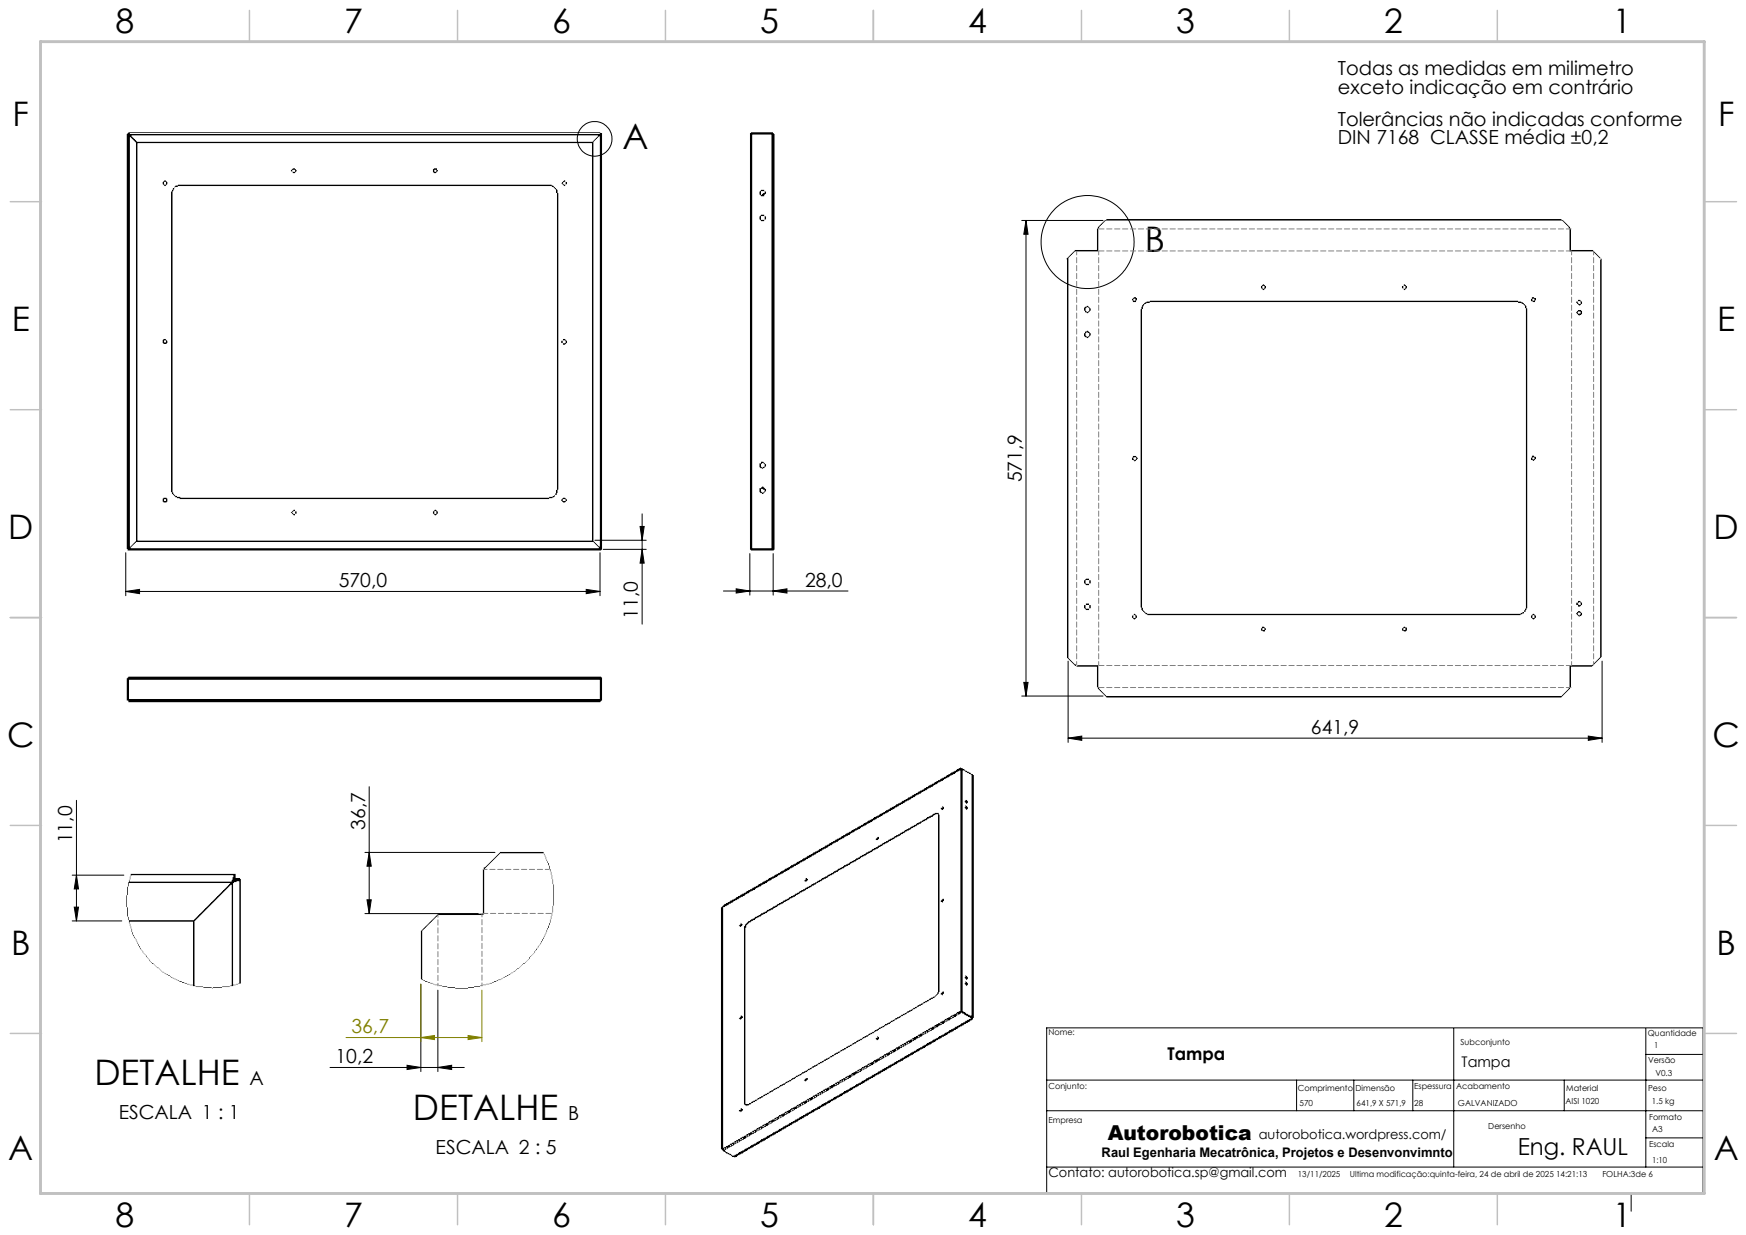
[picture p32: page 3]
DETALHE A; ESCALA 1 : 1; DETALHE B; ESCALA 2 : 5

Tolerâncias não indicadas conforme
DIN 7168 CLASSE média ±0,2

Conjunto: | Comprimento 570 | Dimensão 641,9 X 571,9 | Espessura 28 | Acabamento GALVANIZADO | Material AISI 1020 | Peso 1.5 kg

Empresa Autorobotica autorobotica.wordpress.com/ | | | | Dersenho | | Formato A3

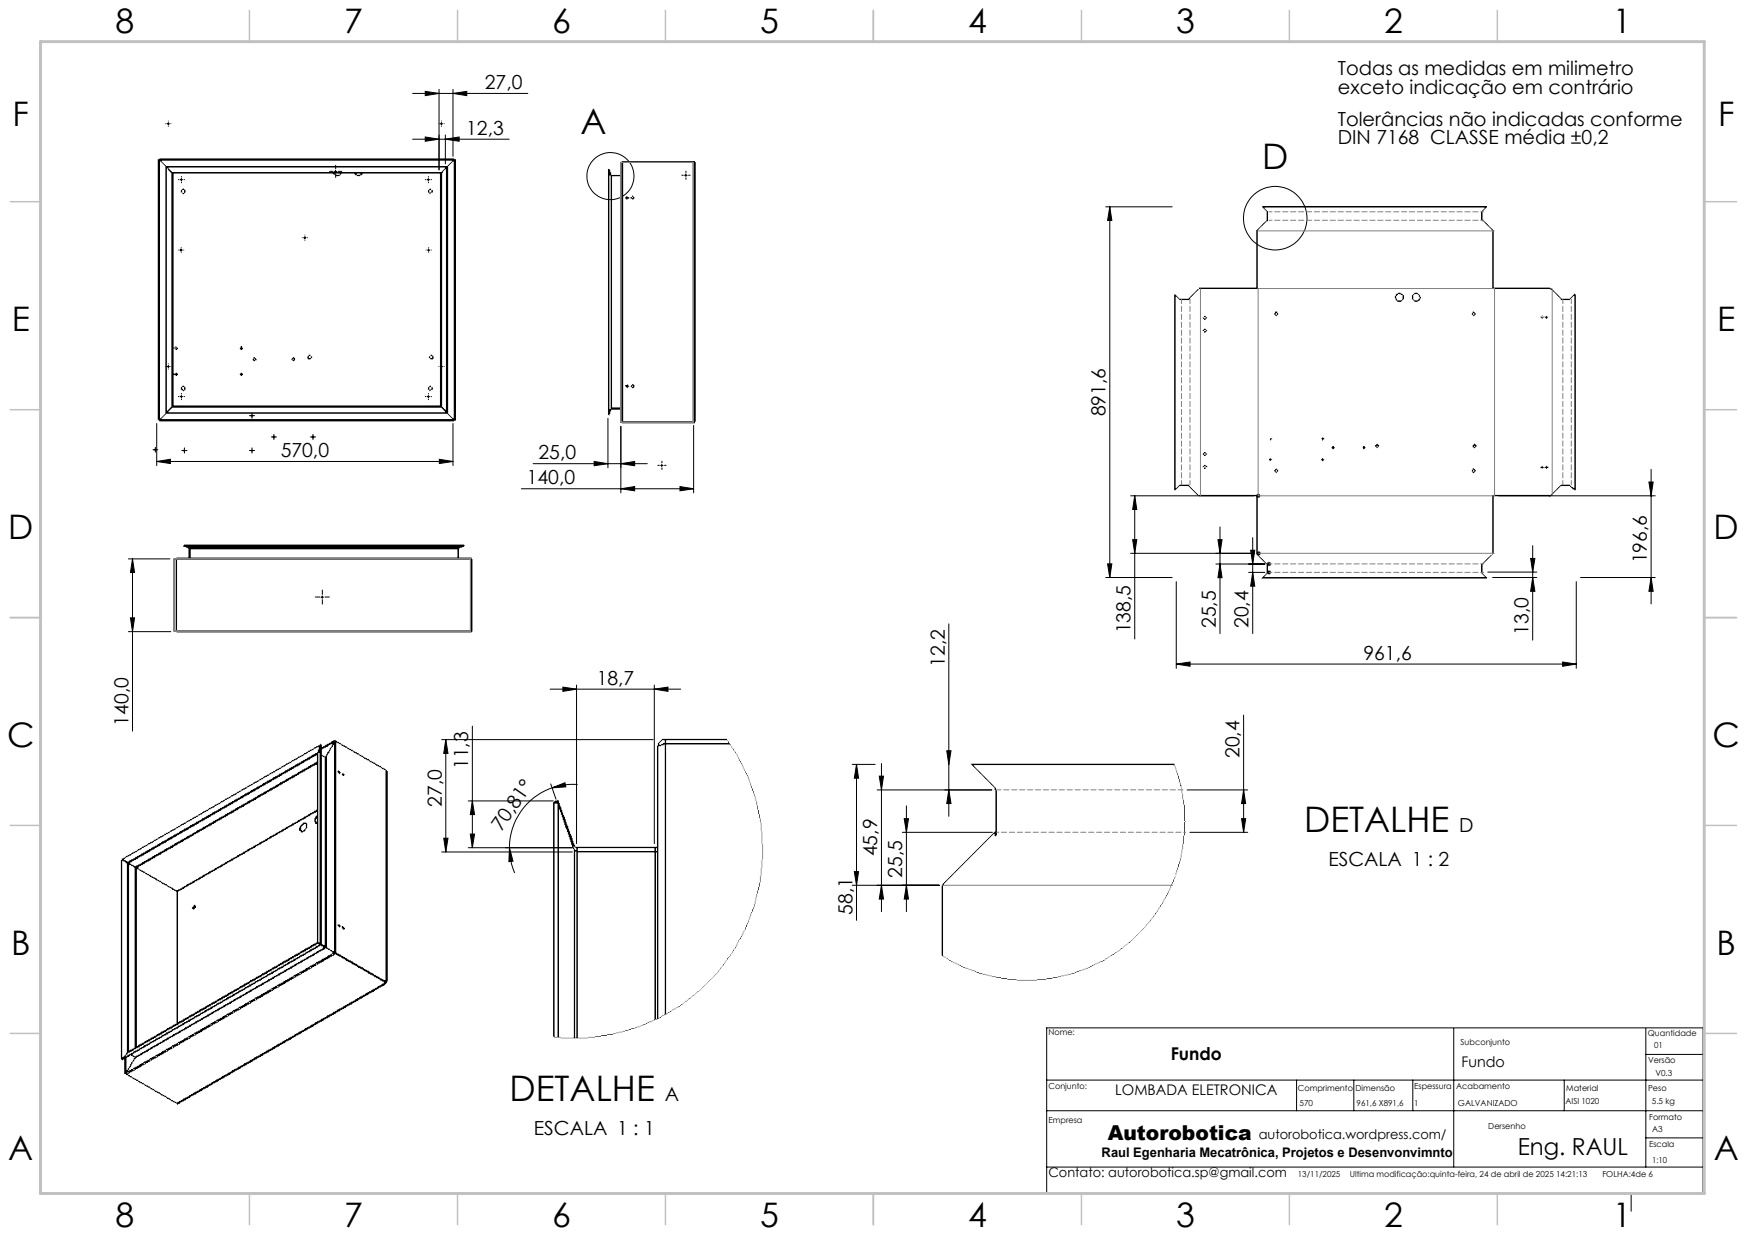
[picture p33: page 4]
ESCALA 1 : 1; ESCALA 1 : 2

Tolerâncias não indicadas conforme
DIN 7168 CLASSE média ±0,2

Conjunto: LOMBADA ELETRONICA | Comprimento 570 | Dimensão 961,6 X891,6 | Espessura 1 | Acabamento GALVANIZADO | Material AISI 1020 | Peso 5.5 kg

Empresa Autorobotica autorobotica.wordpress.com/ | | | | Dersenho | | Formato A3

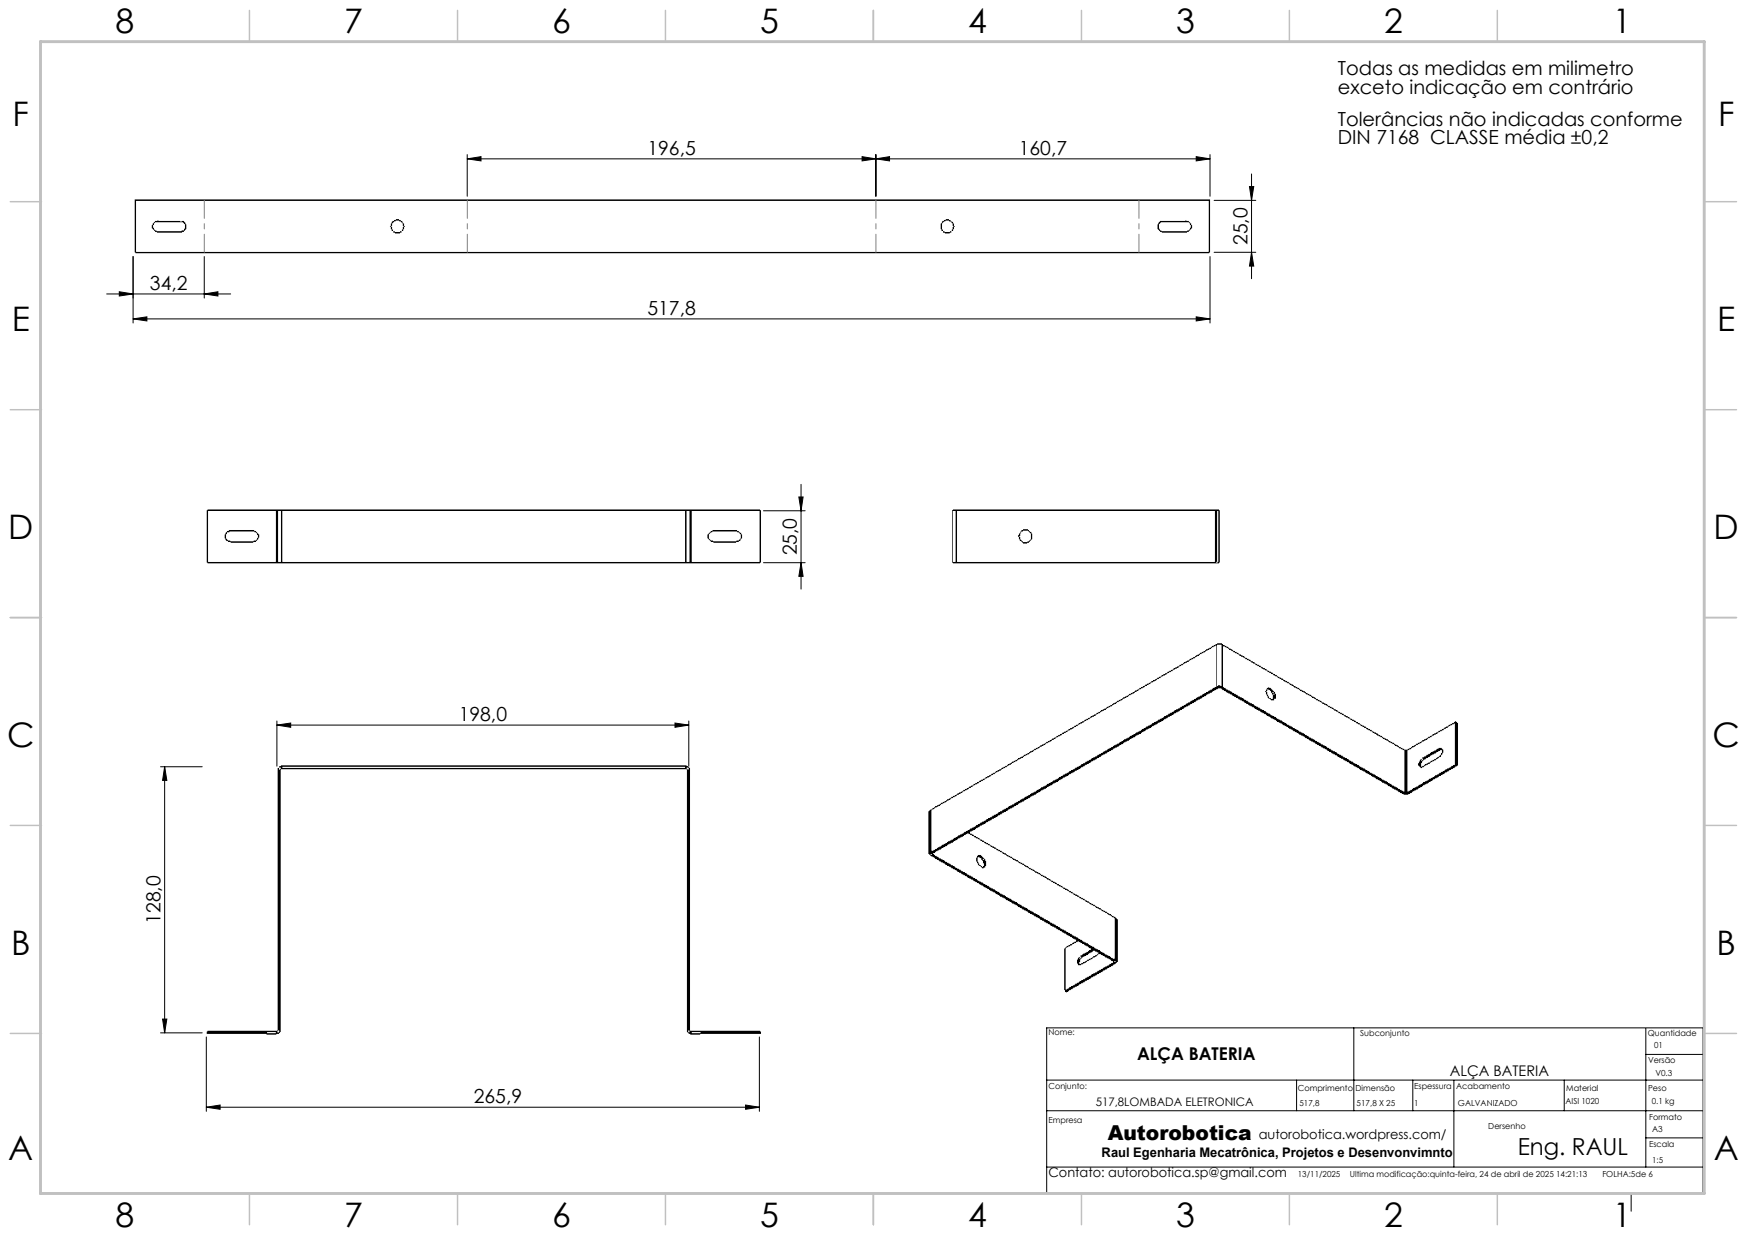
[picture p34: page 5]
ALÇA BATERIA

Tolerâncias não indicadas conforme
DIN 7168 CLASSE média ±0,2

Conjunto: 517,8LOMBADA ELETRONICA | Comprimento 517,8 | Dimensão 517,8 X 25 | Espessura 1 | Acabamento GALVANIZADO | Material AISI 1020 | Peso 0.1 kg

Empresa Autorobotica autorobotica.wordpress.com/ | | | | Dersenho | | Formato A3

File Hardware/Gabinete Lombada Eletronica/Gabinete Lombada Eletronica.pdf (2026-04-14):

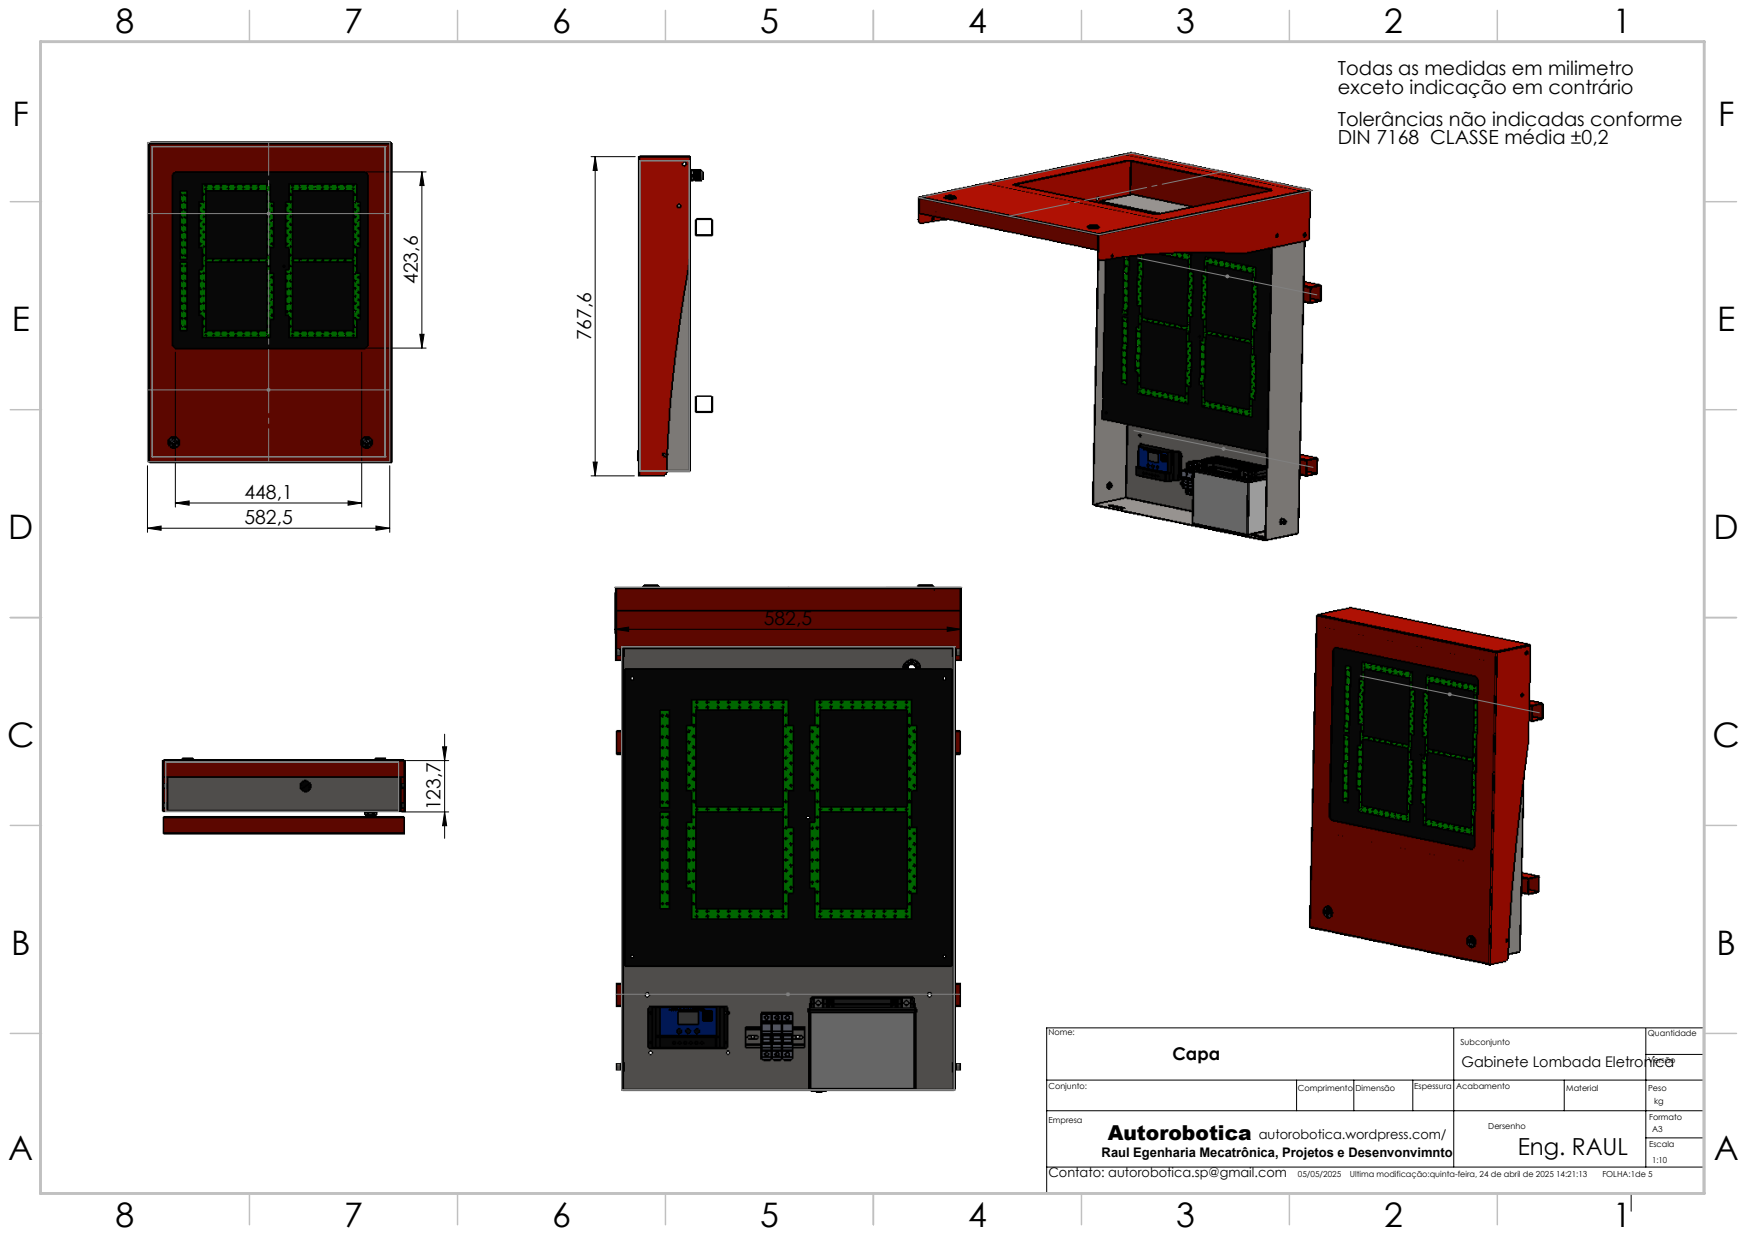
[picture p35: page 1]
Contato: autorobotica.sp@gmail.com; Ultima modificação:quinta-feira, 24 de abril de 2025 14:21:13; FOLHA:1de 5; Capa; Gabinete Lombada Eletronica

Todas as medidas em milimetro
exceto indicação em contrário
Tolerâncias não indicadas conforme
DIN 7168 CLASSE média ±0,2

Conjunto: | Comprimento | Dimensão | Espessura | Acabamento | Material | Peso kg
Empresa Autorobotica autorobotica.wordpress.com/ Raul Egenharia Mecatrônica, Projetos e Desenvonvimnto | | | | Dersenho Eng. RAUL | | Formato A3

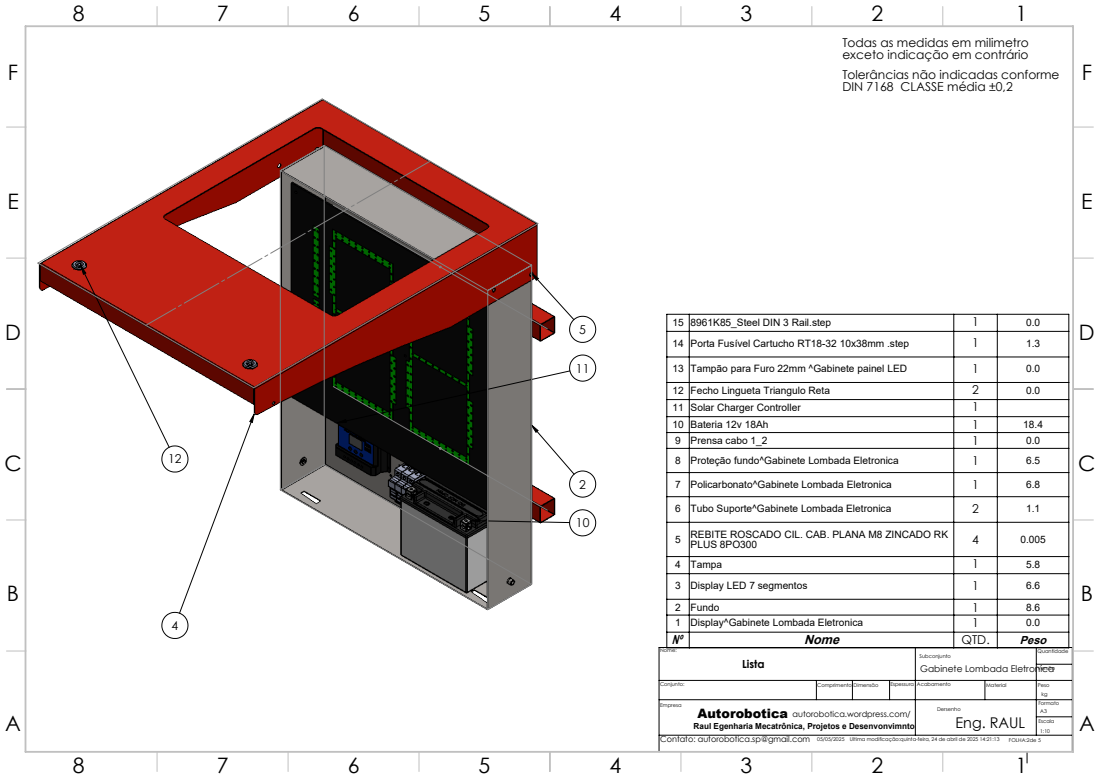
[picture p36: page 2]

Tolerâncias não indicadas conforme
DIN 7168 CLASSE média ±0,2

15 | 8961K85_Steel DIN 3 Rail.step | 1 | 0.0
14 | Porta Fusível Cartucho RT18-32 10x38mm .step | 1 | 1.3
13 | Tampão para Furo 22mm ^Gabinete painel LED | 1 | 0.0
12 | Fecho Lingueta Triangulo Reta | 2 | 0.0
11 | Solar Charger Controller | 1
10 | Bateria 12v 18Ah | 1 | 18.4
9 | Prensa cabo 1_2 | 1 | 0.0
8 | Proteção fundo^Gabinete Lombada Eletronica | 1 | 6.5
7 | Policarbonato^Gabinete Lombada Eletronica | 1 | 6.8
6 | Tubo Suporte^Gabinete Lombada Eletronica | 2 | 1.1

5 | REBITE ROSCADO CIL. CAB. PLANA M8 ZINCADO RK PLUS 8PO300 | 4 | 0.005

4 | Tampa | 1 | 5.8
3 | Display LED 7 segmentos | 1 | 6.6
2 | Fundo | 1 | 8.6
1 | Display^Gabinete Lombada Eletronica | 1 | 0.0
Nº | Nome | QTD. | Peso

Nome: Lista | Subconjunto Gabinete Lombada Eletronica | Quantidade

Conjunto: | Comprimento | Dimensão | Espessura | Acabamento | Material | Peso kg

Empresa Autorobotica autorobotica.wordpress.com/ | | | | Dersenho | | Formato A3

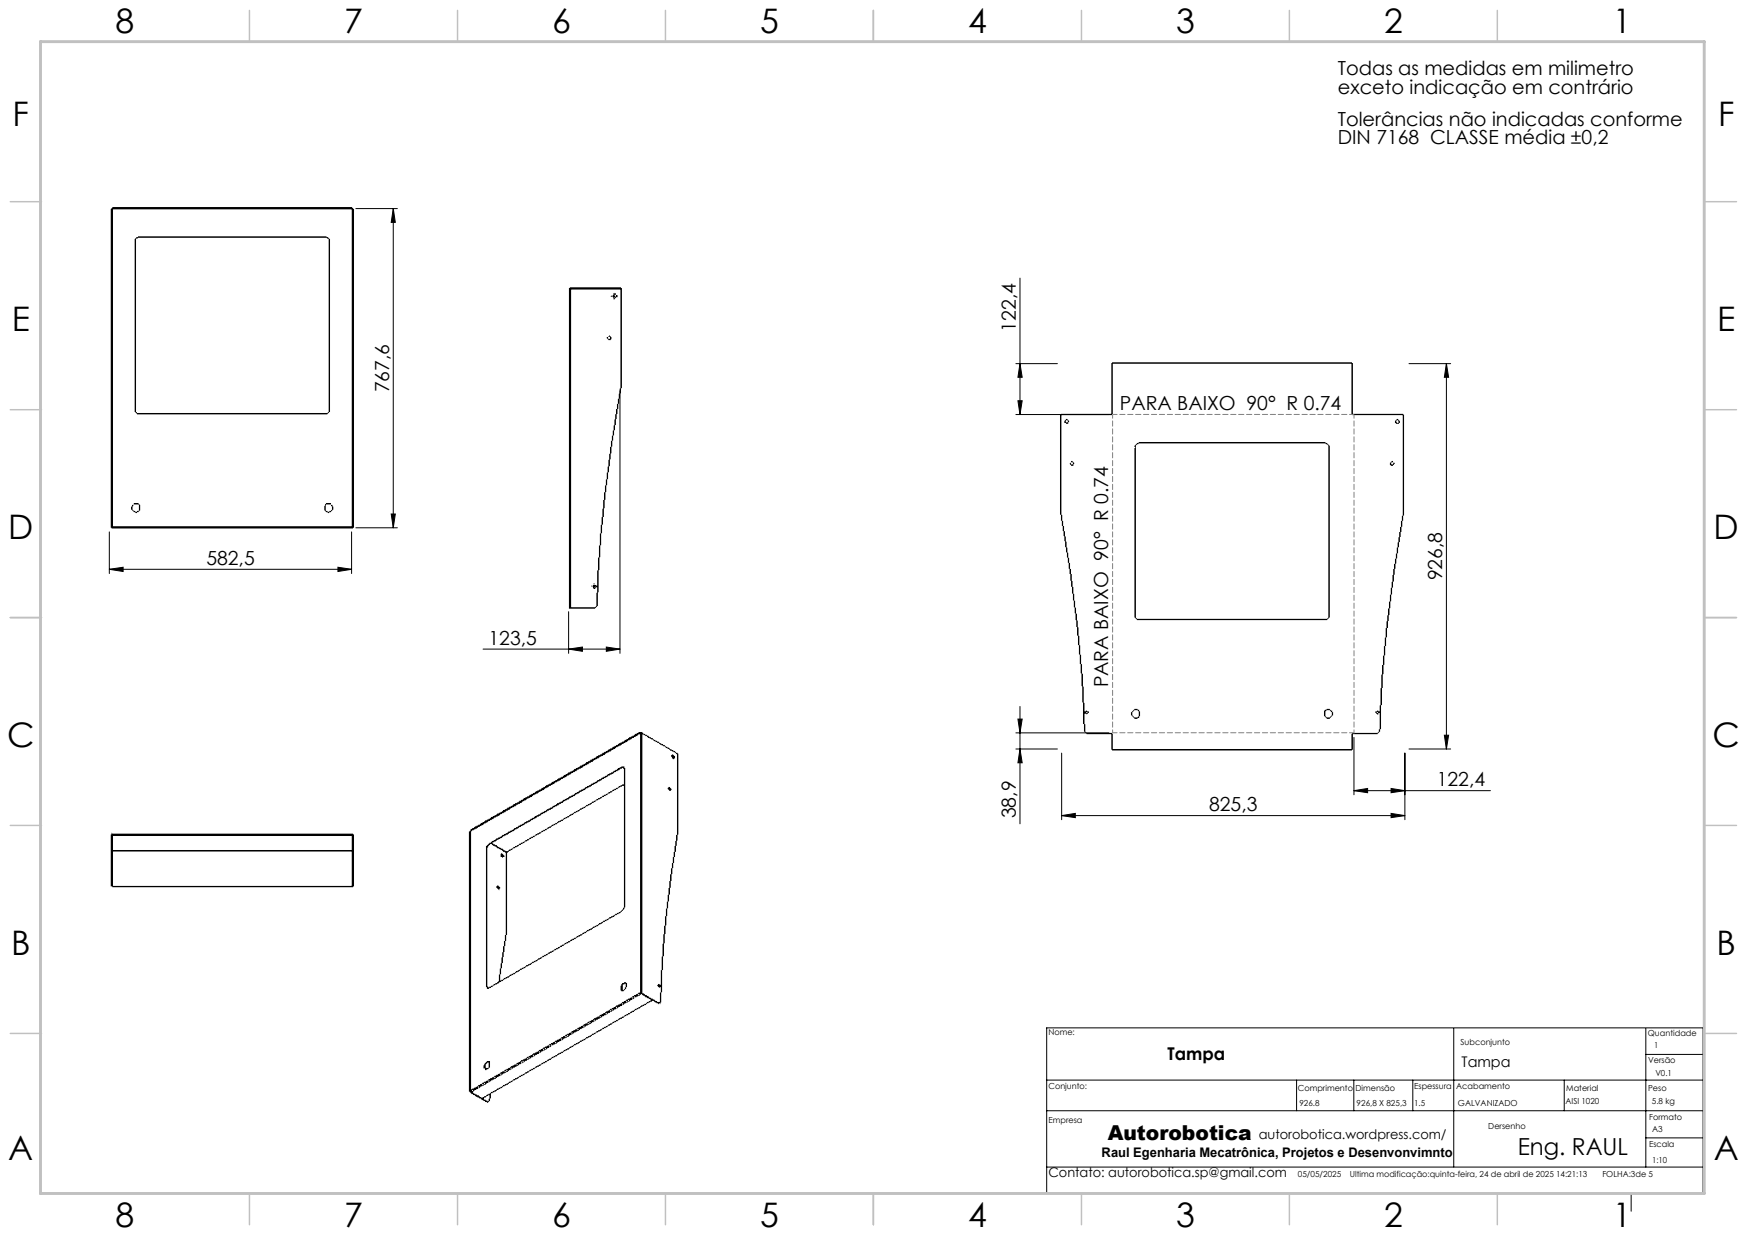
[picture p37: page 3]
PARA BAIXO 90° R 0.74

Tolerâncias não indicadas conforme
DIN 7168 CLASSE média ±0,2

Conjunto: | Comprimento 926.8 | Dimensão 926,8 X 825,3 | Espessura 1.5 | Acabamento GALVANIZADO | Material AISI 1020 | Peso 5.8 kg

Empresa Autorobotica autorobotica.wordpress.com/ | | | | Dersenho | | Formato A3

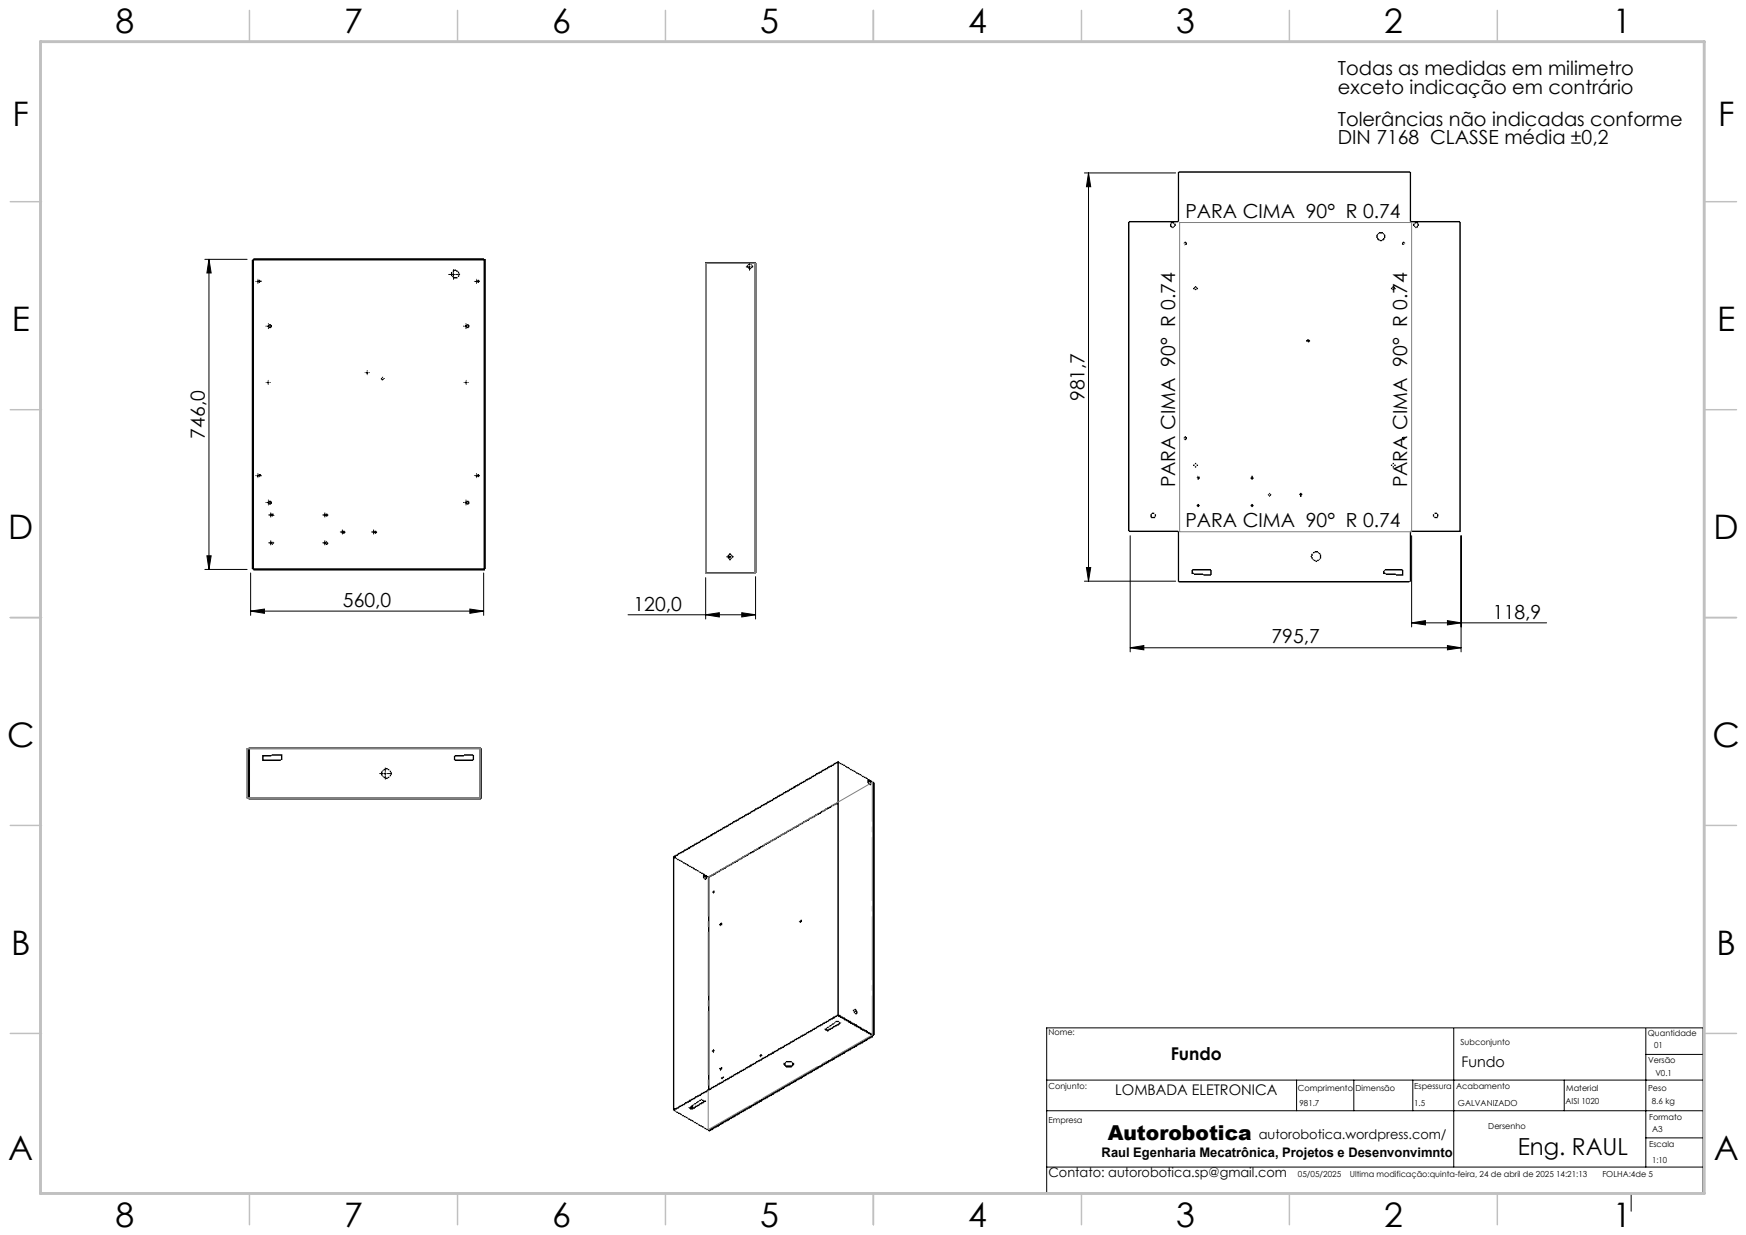
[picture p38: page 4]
PARA CIMA 90° R 0.74

Tolerâncias não indicadas conforme
DIN 7168 CLASSE média ±0,2

PARA CIMA 90° R 0.74

Conjunto: LOMBADA ELETRONICA | Comprimento 981.7 | Dimensão | Espessura 1.5 | Acabamento GALVANIZADO | Material AISI 1020 | Peso 8.6 kg

Empresa Autorobotica autorobotica.wordpress.com/ | | | | Dersenho | | Formato A3

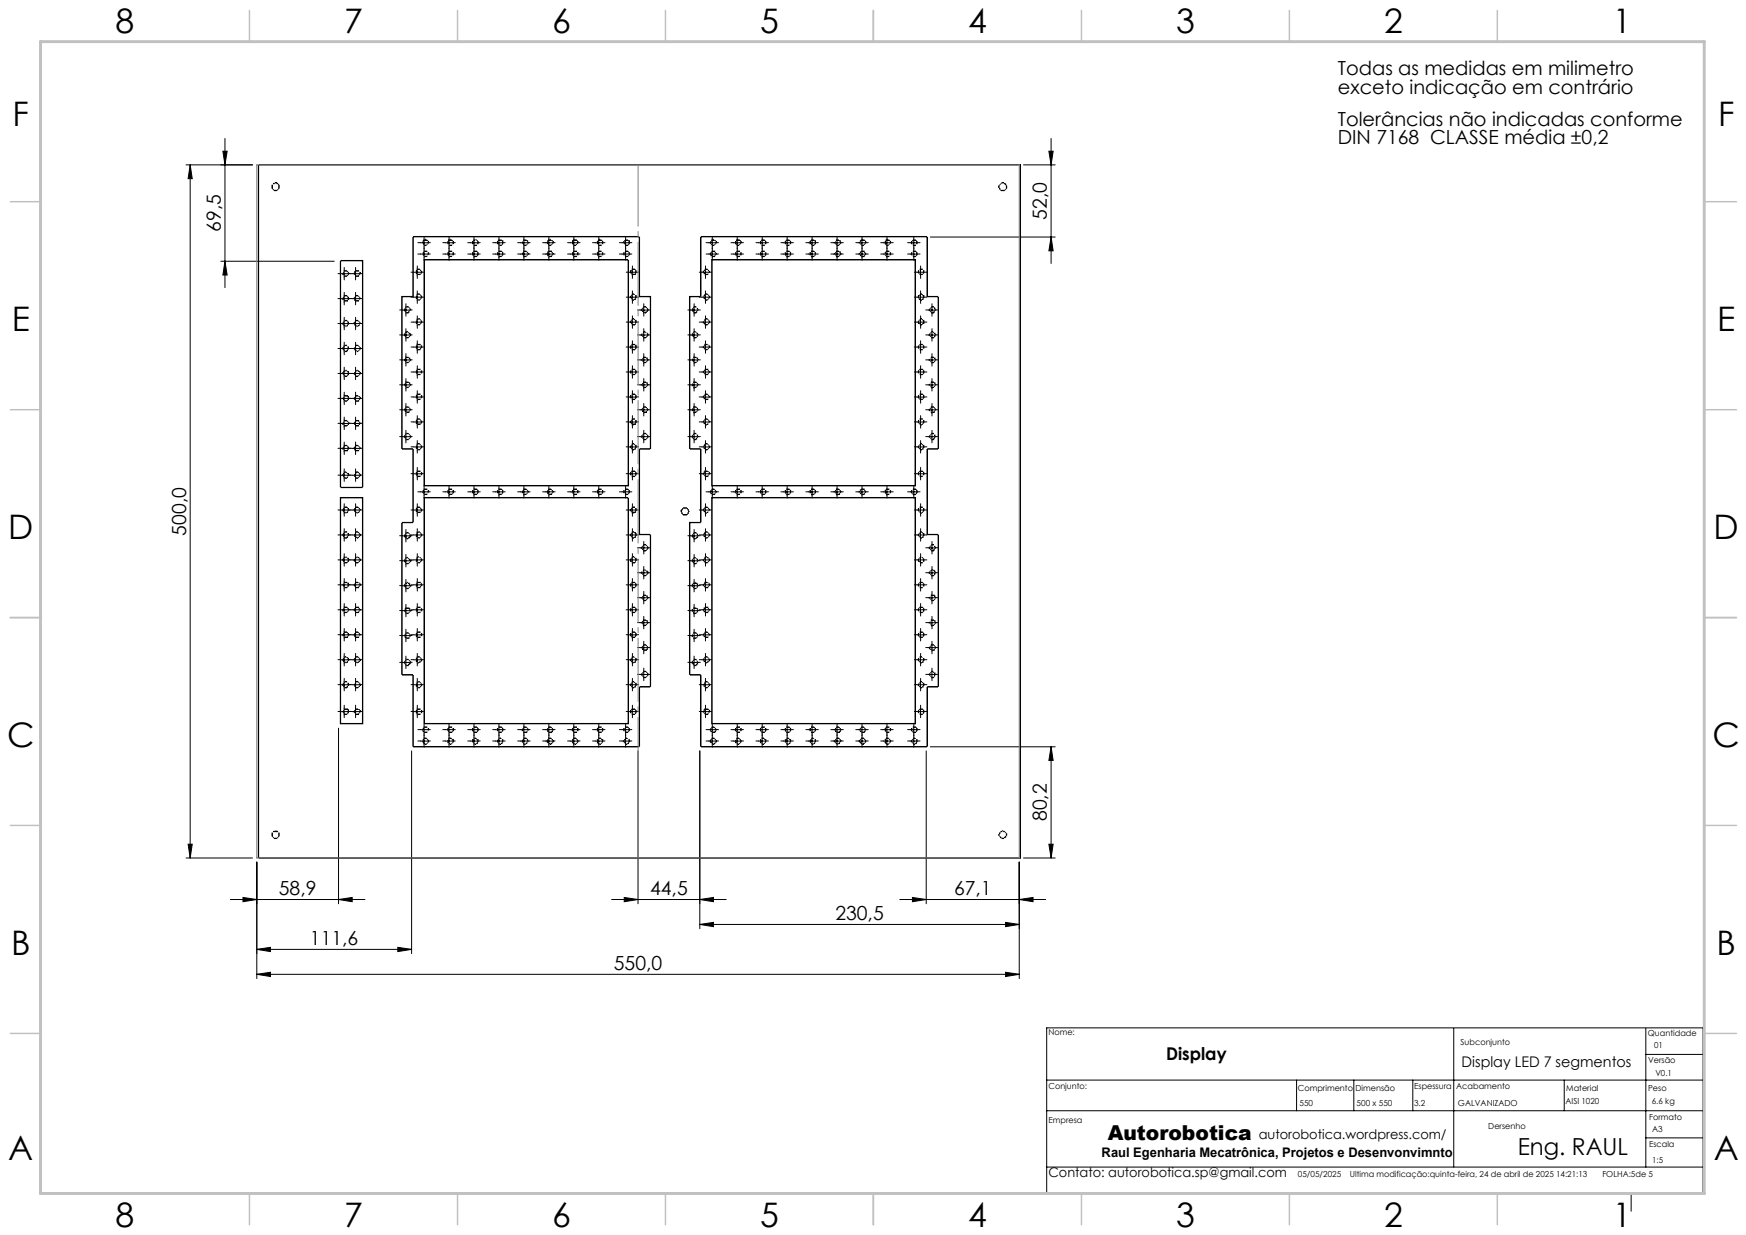
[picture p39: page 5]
Display; Display LED 7 segmentos

Tolerâncias não indicadas conforme
DIN 7168 CLASSE média ±0,2

Conjunto: | Comprimento 550 | Dimensão 500 x 550 | Espessura 3.2 | Acabamento GALVANIZADO | Material AISI 1020 | Peso 6.6 kg

Empresa Autorobotica autorobotica.wordpress.com/ | | | | Dersenho | | Formato A3

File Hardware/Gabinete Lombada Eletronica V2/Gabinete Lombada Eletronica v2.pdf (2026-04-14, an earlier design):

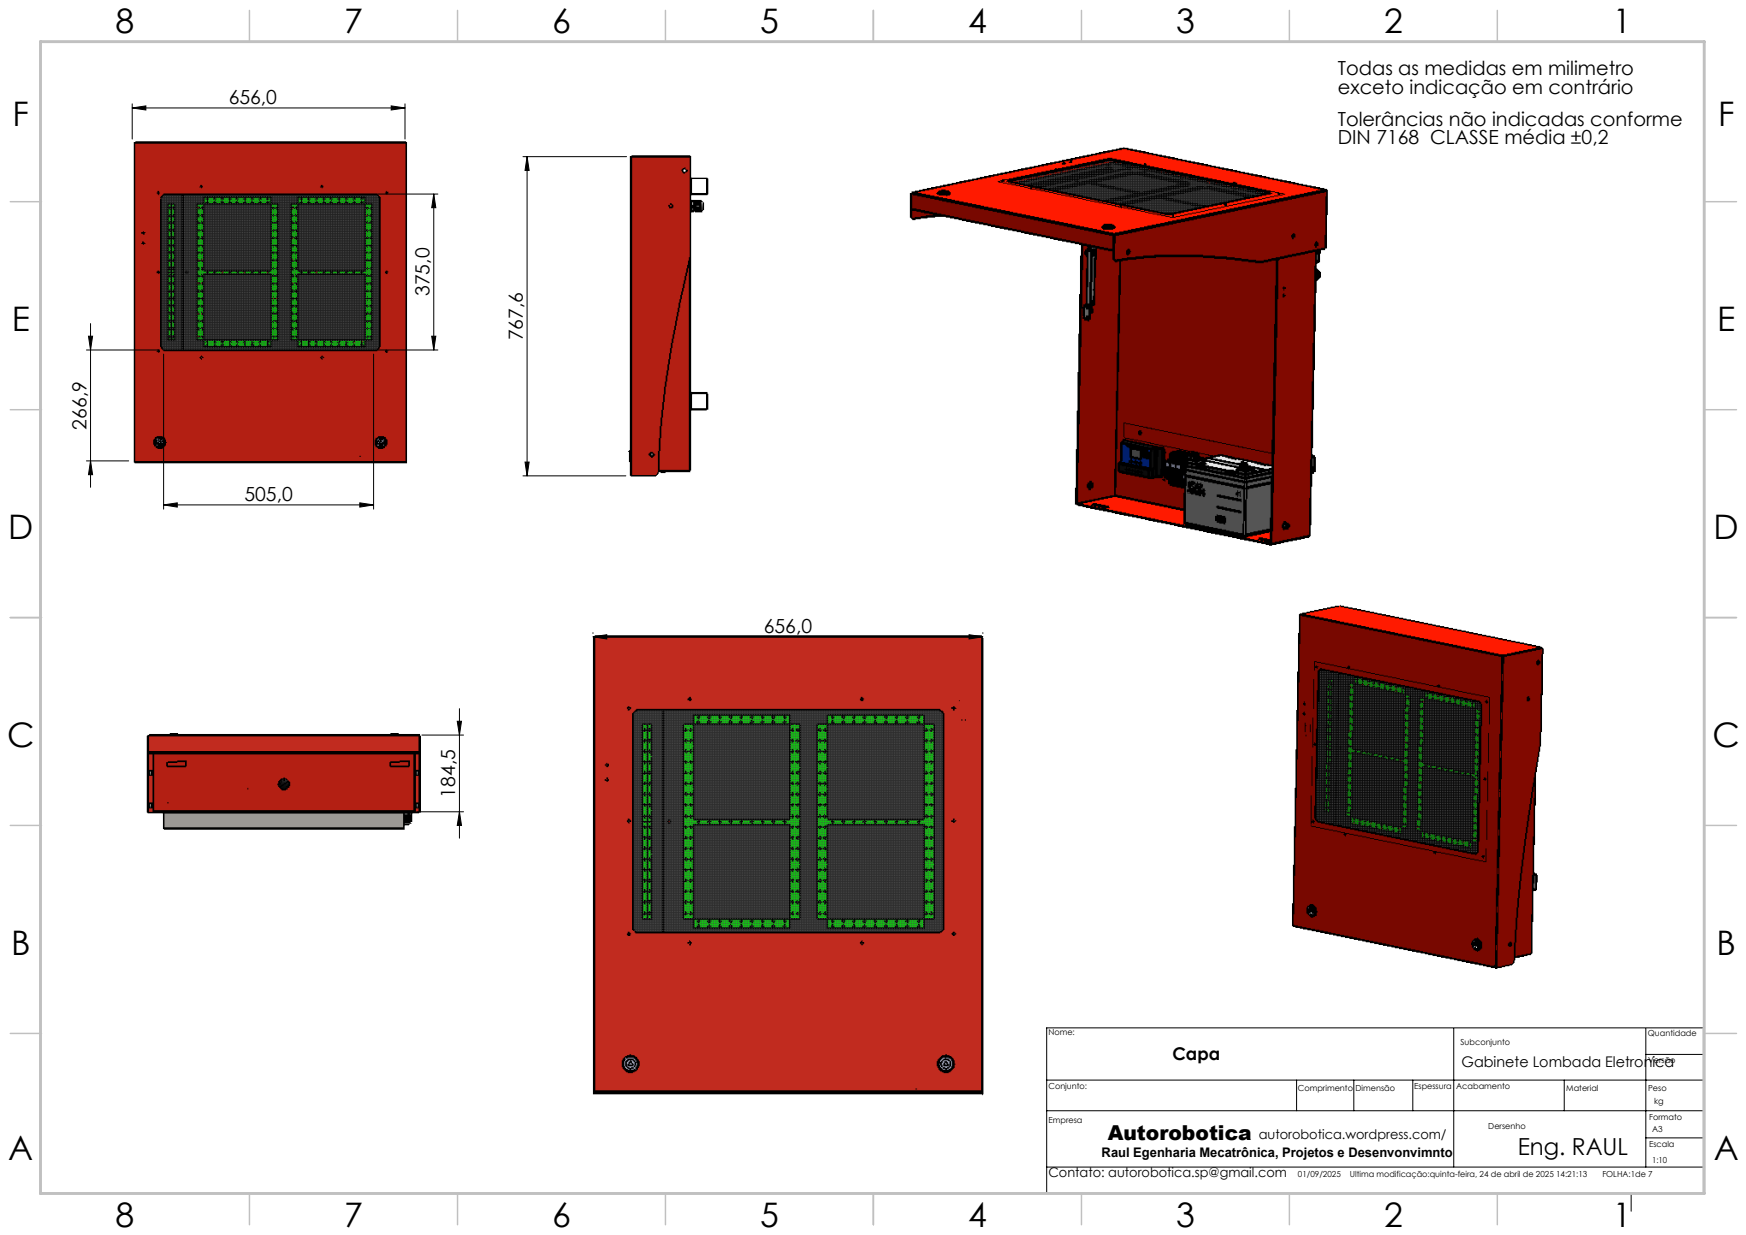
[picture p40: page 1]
Contato: autorobotica.sp@gmail.com; Ultima modificação:quinta-feira, 24 de abril de 2025 14:21:13; FOLHA:1de 7; Capa; Gabinete Lombada Eletronica

Todas as medidas em milimetro
exceto indicação em contrário
Tolerâncias não indicadas conforme
DIN 7168 CLASSE média ±0,2

Conjunto: | Comprimento | Dimensão | Espessura | Acabamento | Material | Peso kg
Empresa Autorobotica autorobotica.wordpress.com/ Raul Egenharia Mecatrônica, Projetos e Desenvonvimnto | | | | Dersenho Eng. RAUL | | Formato A3

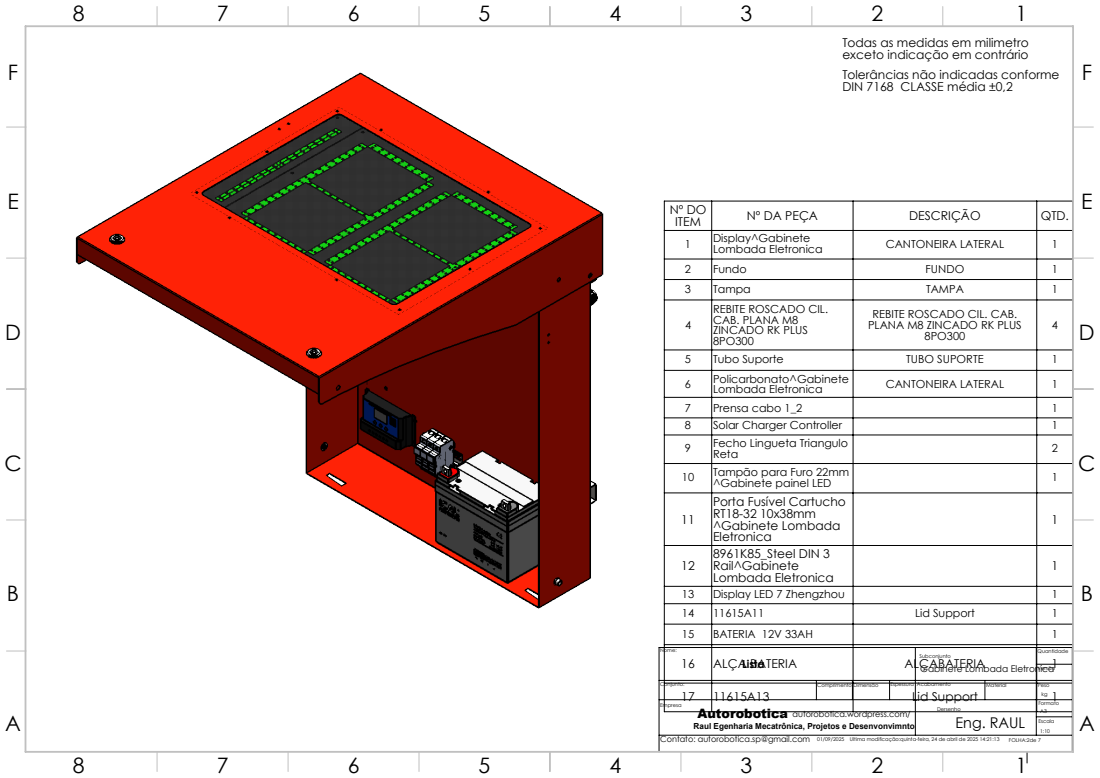
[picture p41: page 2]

Tolerâncias não indicadas conforme
DIN 7168 CLASSE média ±0,2

Nº DO ITEM | Display^Gabinete Nº DA PEÇA | DESCRIÇÃO | QTD. 1

Lombada Eletronica | CANTONEIRA LATERAL | 1
2 | Fundo | FUNDO | 1
3 | Tampa | TAMPA | 1
4 | REBITE ROSCADO CIL. CAB. PLANA M8 ZINCADO RK PLUS 8PO300 | REBITE ROSCADO CIL. CAB. PLANA M8 ZINCADO RK PLUS 8PO300 | 4

5 | Tubo Suporte | TUBO SUPORTE | 1
6 | Policarbonato^Gabinete Lombada Eletronica | CANTONEIRA LATERAL | 1

7 | Prensa cabo 1_2 | | 1
8 | Solar Charger Controller | | 1
9 | Fecho Lingueta Triangulo Reta | | 2
10 | Tampão para Furo 22mm ^Gabinete painel LED | | 1
11 | Porta Fusível Cartucho RT18-32 10x38mm ^Gabinete Lombada Eletronica | | 1

12 | 8961K85_Steel DIN 3 Rail^Gabinete Lombada Eletronica | | 1

13 | Display LED 7 Zhengzhou | | 1
14 | 11615A11 | Lid Support | 1
15 | BATERIA 12V 33AH | | 1
Nome: | 16 | ALÇA BATERIA Lista | ALÇABATERIA | Subconjunto Gabinete Lombada Eletronica | Quantidade 1

Conjunto:
17 | 11615A13 | Comprimento | Dimensão | Espessura Lid Support | Acabamento | Material | Peso 1 kg

Empresa | Autorobotica autorobotica.wordpress.com/ | | | | | Dersenho | | Formato A3


Tolerâncias não indicadas conforme
DIN 7168 CLASSE média ±0,2

Conjunto: | Comprimento 767.6 | Dimensão 948,0 X 939,9 | Espessura 143.5 | Acabamento GALVANIZADO | Material AISI 1020 | Peso 4.7 kg

Empresa Autorobotica autorobotica.wordpress.com/ | | | | Dersenho | | Formato A3


Tolerâncias não indicadas conforme
DIN 7168 CLASSE média ±0,2

Conjunto: LOMBADA ELETRONICA | Comprimento 981.7 | Dimensão | Espessura 1 | Acabamento GALVANIZADO | Material AISI 1020 | Peso 6.7 kg

Empresa Autorobotica autorobotica.wordpress.com/ | | | | Dersenho | | Formato A3

ALÇA BATERIA

Tolerâncias não indicadas conforme
DIN 7168 CLASSE média ±0,2

Conjunto: 517,8LOMBADA ELETRONICA | Comprimento 517,8 | Dimensão 517,8 X 25 | Espessura 1 | Acabamento GALVANIZADO | Material AISI 1020 | Peso 0.1 kg

Empresa Autorobotica autorobotica.wordpress.com/ | | | | Dersenho | | Formato A3

Folha1; Tubo Suporte

Tolerâncias não indicadas conforme
DIN 7168 CLASSE média ±0,2

Conjunto: LOMBADA | Comprimento 578.1 | Dimensão 40 X 40 | Espessura 40 | Acabamento NATURAL | Material AISI 1020 | Peso 2.1 kg

Empresa Autorobotica autorobotica.wordpress.com/ | | | | Dersenho | | Formato A3

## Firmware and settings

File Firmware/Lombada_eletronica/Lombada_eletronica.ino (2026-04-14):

//////////////////////////////////////////////////////////////////////////////////////////////////////////////
//                                        Lombada eletrônica
//
//   build 18/03/2025 by Raul
//  v0.7
//  Arduino IDE 2.3.3
//  platform = atmelavr
//  board = nanoatmega328
//  framework = Arduino IDE 2.3.3
//       @site:www.autorobotica.sp@gmail.com
//       @email: raulstar3@gmail.com ,
//       www.linkedin.com/in/raulstar/, Instagram: @raulstar3,github.com/raulstar
//
//  consiste em um radar de microondas LDS 306s de  21,1 GHz, e se comunica com o Arduino NANO atmega328p via interface RS 485,
//  usando uma fita LED interessada ws2811, são emulados um display de 7 segmento que exibe a velocidade.
//////////////////////////////////////////////////////////////////////////////////////////////////////////////
// mapeamento de hardware
#include <SoftwareSerial.h>  //1.0
#include <FastLED.h>         //FastLED 3.9.15
#define NUM_LEDS 67
#define DATA_PIN 4
#define um 3
#define alerta 2
#define positivo A0
#define ajustePin A7
#define negativo A2

//////////////////////////////////////////////////////////////////////////////////////////////////////////////
// macros
#define petenciometroVelocMax analogRead(ajustePin)
#define potenciometro5v digitalWrite(positivo, HIGH)
#define potenciometroGND digitalWrite(negativo, LOW)

//////////////////////////////////////////////////////////////////////////////////////////////////////////////
// variáveis
int vermelho = 0;
int verde = 0;
int azul = 255;
int velocidade_varre = 0;
int comtador;
char seguimento;
int brilho = 255;
int velocidade_minima = 1;
int velocidade_maxima = 160;
unsigned long limpaDisplay = 8000;
int contagem = 0;
int leitura = 0;
int dado = 0;
int velocidade = 0;
unsigned long tempo = 0;
const unsigned long reinicioContagem = 500;

CRGB leds[NUM_LEDS];
SoftwareSerial mySerial(3, 2);

//////////////////////////////////////////////////////////////////////////////////////////////////////////////
// prototipo Funções
void Unidade(int nun);
void Decodifica(int numero);
void Seguimento(bool multiplo, char s);
void contaTempo(int _tempo);
void Numero(int);
void Radar(void);
bool Manual(void);
void Envia(void);
void teste(void);
void CalculaVelocidade(int _leitura, int _reinicioContagem, int _contagem);
void corDoDisplay(int velocidade, int _tempo);

//////////////////////////////////////////////////////////////////////////////////////////////////////////////
// Confiruração
void setup() {
  pinMode(positivo, OUTPUT);
  pinMode(ajustePin, INPUT);
  pinMode(negativo, OUTPUT);

  potenciometro5v;
  potenciometroGND;

  FastLED.addLeds<WS2811, DATA_PIN>(leds, NUM_LEDS);
  FastLED.setBrightness(brilho);
  mySerial.begin(9600);
  Serial.begin(115200);
  Serial.println("Pronto");
  Decodifica(188);
  delay(500);
  vermelho = 0, verde = 0, azul = 0;
  FastLED.clear();
  Decodifica(0);


  //     for (int i = 0; i <120; i++) {
  //     FastLED.clear();
  //     Decodifica(i);
  //     Serial.println(i);
  //     delay(5);
  //   }
}

//////////////////////////////////////////////////////////////////////////////////////////////////////////////
// Loop Principal
void loop() {
  //vermelho = 255, verde = 0, azul = 0;
  //Seguimento(1, 'h');
  corDoDisplay(velocidade, tempo);
  Radar();
  contaTempo(tempo);
  if (tempo > limpaDisplay) {
    CalculaVelocidade(leitura, reinicioContagem, contagem);
  }
  //Serial.println(tempo);
}

//////////////////////////////////////////////////////////////////////////////////////////////////////////////
//Funçoes
void Seguimento(int multiplo, char s) {
  int digito = 0;

  if (multiplo >= 1) digito = 21;
  switch (s) {

    case 'a':
      for (int i = 0; i < 3; i++) {
        leds[i + digito] = CRGB(vermelho, verde, azul);
        //Serial.print(i);
        FastLED.show();
        delay(velocidade_varre);
      }
      break;

    case 'b':
      for (int i = 3; i < 6; i++) {
        leds[i + digito] = CRGB(vermelho, verde, azul);
        //Serial.print(i);
        FastLED.show();
        delay(velocidade_varre);
      }
      break;

    case 'c':
      for (int i = 6; i < 9; i++) {
        leds[i + digito] = CRGB(vermelho, verde, azul);
        FastLED.show();
        //delay(velocidade_varre);
      }
      break;
    case 'd':
      for (int i = 9; i < 12; i++) {
        leds[i + digito] = CRGB(vermelho, verde, azul);
        FastLED.show();
        delay(velocidade_varre);
      }
      break;
    case 'e':
      for (int i = 12; i < 15; i++) {
        leds[i + digito] = CRGB(vermelho, verde, azul);
        FastLED.show();
        delay(velocidade_varre);
      }
      break;
    case 'f':
      for (int i = 15; i < 18; i++) {
        leds[i + digito] = CRGB(vermelho, verde, azul);
        FastLED.show();
        delay(velocidade_varre);
      }
      break;
    case 'g':
      for (int i = 18; i < 21; i++) {
        leds[i + digito] = CRGB(vermelho, verde, azul);
        FastLED.show();
        delay(velocidade_varre);
      }
      break;
    case 'h':
      for (int i = 42; i < 48; i++) {  //  for (int i = 42; i < 51; i++) {
        leds[i + digito] = CRGB(vermelho, verde, azul);
        FastLED.show();
        delay(velocidade_varre);
      }
      break;
  }
}
//////////////////////////////////////////////////////////////////////////////////////////////////////////////
//
void Decodifica(int numero) {
  int multiplo = 0;
  int varredura = 2;
  int centena = 0;
  if (numero > 99) {
    numero = numero - 100;
    centena = 1;
  }
  //Serial.println(numero);
  int dezena = numero / 10;
  int unidade = numero % 10;

  numero = unidade;

  for (int i = 0; i < (varredura + 1); i++) {
    //int digito = unidade;
    switch (numero) {
      case 0:
        Seguimento(multiplo, 'a');
        Seguimento(multiplo, 'b');
        Seguimento(multiplo, 'c');
        Seguimento(multiplo, 'd');
        Seguimento(multiplo, 'e');
        Seguimento(multiplo, 'f');
        FastLED.show();
        break;
      case 1:
        Seguimento(multiplo, 'b');
        Seguimento(multiplo, 'c');
        FastLED.show();
        break;
      case 2:
        Seguimento(multiplo, 'a');
        Seguimento(multiplo, 'b');
        Seguimento(multiplo, 'd');
        Seguimento(multiplo, 'e');
        Seguimento(multiplo, 'g');
        FastLED.show();
        break;
      case 3:
        Seguimento(multiplo, 'a');
        Seguimento(multiplo, 'b');
        Seguimento(multiplo, 'c');
        Seguimento(multiplo, 'd');
        Seguimento(multiplo, 'g');
        FastLED.show();
        break;
      case 4:
        Seguimento(multiplo, 'b');
        Seguimento(multiplo, 'c');
        Seguimento(multiplo, 'f');
        Seguimento(multiplo, 'g');
        FastLED.show();
        break;
      case 5:
        Seguimento(multiplo, 'a');
        Seguimento(multiplo, 'c');
        Seguimento(multiplo, 'd');
        Seguimento(multiplo, 'f');
        Seguimento(multiplo, 'g');
        FastLED.show();
        break;
      case 6:
        Seguimento(multiplo, 'a');
        Seguimento(multiplo, 'c');
        Seguimento(multiplo, 'd');
        Seguimento(multiplo, 'e');
        Seguimento(multiplo, 'f');
        Seguimento(multiplo, 'g');
        break;
      case 7:
        Seguimento(multiplo, 'a');
        Seguimento(multiplo, 'b');
        Seguimento(multiplo, 'c');
        FastLED.show();
        break;
      case 8:
        Seguimento(multiplo, 'a');
        Seguimento(multiplo, 'b');
        Seguimento(multiplo, 'c');
        Seguimento(multiplo, 'd');
        Seguimento(multiplo, 'e');
        Seguimento(multiplo, 'f');
        Seguimento(multiplo, 'g');
        FastLED.show();
        break;
      case 9:
        Seguimento(multiplo, 'a');
        Seguimento(multiplo, 'b');
        Seguimento(multiplo, 'c');
        Seguimento(multiplo, 'd');
        Seguimento(multiplo, 'f');
        Seguimento(multiplo, 'g');
        FastLED.show();
        break;
        FastLED.show();
        break;
    }
    if (centena == 1) {
      Seguimento(multiplo, 'h');
      centena = 0;
    }
    if (dezena > 0) {
      multiplo = 1;
      numero = dezena;
    } else {
      multiplo = 0;
    }
  }
}
//////////////////////////////////////////////////////////////////////////////////////////////////////////////

void Envia() {

  int value = 0;
  int loop_time = 87;

  // escreve o resultado
  if (Serial.availableForWrite()) {
    String outstr = String(String(leitura, DEC) + "," + String(loop_time, DEC) + "," + String(value, DEC));
    Serial.println(outstr);
    Serial.flush();
  }
}

/////////////////////////////////////////////////////////////////////////////////////////
void Radar(void) {

  while (mySerial.available() >= 12) {  // Verifica se há 12 bytes disponíveis
    byte dados[12];                     // Array para armazenar os dados recebidos
    mySerial.readBytes(dados, 12);      // Lê 12 bytes da porta serial
  
    if (dados[1] == 85) {
      for (int i = 0; i < 12; i++) {
        dado = dados[i];  // Converte o byte para inteiro
        //Serial.println(dado);
        if (i == 6) {  // Imprime o sexto elemento do array
          leitura = dado;
          //vermelho = 255, verde = 0, azul = 0;
          if ((leitura > velocidade_minima) && (leitura < velocidade_maxima)) {
            contagem++;
            //vermelho = 255, verde = 0, azul = 0;
            CalculaVelocidade(leitura, reinicioContagem, contagem);
          }
        }
      }
    }
    //Serial.println("");
  }
}

/////////////////////////////////////////////////////////////////////////////////////////
void CalculaVelocidade(int _leitura, int _reinicioContagem, int _contagem) {
  static int velocidades[3];
  static int passo = 0;
  static int ultimaLeitura = 0;
  int difetencaVelocidades = 10;
  //Serial.println(contagem);
  if (contagem) {
    switch (passo) {
      case 0:
        velocidades[0] = leitura;
        ultimaLeitura = leitura;
        //Serial.println(leitura);
        passo = 1;
        break;
      case 1:
        if (contagem > 1) {
          velocidades[1] = leitura;
          //Serial.println(velocidade);
          if ((velocidades[1] <= (velocidades[0] + difetencaVelocidades))
              && (velocidades[1] >= (velocidades[0] - difetencaVelocidades))) {
            velocidade = (velocidades[0] + velocidades[1]) / 2;
            Serial.println(velocidade);
            Decodifica(velocidade);
            tempo = 0;
            passo = 2;
          } else {
            tempo = 0;
            passo = 2;
            Serial.println("divergente");
          }
        }
        break;
      case 2:
        //Serial.println(tempo);
        if (tempo > reinicioContagem) {
          tempo = 0;
          passo = 0;
          contagem = 0;
          velocidade = 0;
          velocidades[0] = 0;
          velocidades[1] = 0;
          velocidades[2] = 0;
          velocidades[3] = 0;
          //Decodifica(0);
          //vermelho = 0, verde = 0, azul = 0;
          //CRGB(azul, verde, vermelho);
          vermelho = 0, verde = 0, azul = 0;
          FastLED.clear();
          Decodifica(0);
          Serial.println("aguardando");
        }
        break;
    }
  }
}
/////////////////////////////////////////////////////////////////////////////////////////
void corDoDisplay(int velocidade, int _tempo) {
  int velociDefinida = 0;
  int VelocMax = 150;
  static int ultimaVelociDefinida = 0;
  static int flag = 0;
  const int tolerancia = 50;
  const int tempoPersistencia = 10;


  velociDefinida = map(petenciometroVelocMax, 0, 1023, 0, VelocMax);
  velociDefinida = round(velociDefinida / 5) * 5;

  if ((flag > 0) && (tempo > tempoPersistencia)) {
    Serial.println("normal");
    FastLED.clear();
    velocidade = 0;
    vermelho = 0, verde = 0, azul = 0;
    CRGB(vermelho, verde, azul);
    FastLED.show();
    flag = 0;
    FastLED.clear();
  }

  if ((flag == 1) || (velociDefinida != ultimaVelociDefinida)) {
    velociDefinida = map(petenciometroVelocMax, 0, 1023, 0, VelocMax);
    velociDefinida = round(velociDefinida / 5) * 5;
    vermelho = 0, verde = 255, azul = 0;
    FastLED.show();
    FastLED.clearData();

    Decodifica(velociDefinida);
    Serial.println(velociDefinida);
    FastLED.show();
  }
  if ((flag == 0) && (velociDefinida != ultimaVelociDefinida)) {
    tempo = 0;
    flag = 1;
    ultimaVelociDefinida = velociDefinida;
    //vermelho = 255, verde = 0, azul = 0;
    Serial.println("nova velocidade");
    Serial.println(velociDefinida);
    vermelho = 0, verde = 255, azul = 0;
    CRGB(vermelho, verde, azul);
    Decodifica(velociDefinida);
    FastLED.show();
  }



  ultimaVelociDefinida = velociDefinida;

  if (velociDefinida <= velocidade) {
     vermelho = 0, verde = 255, azul = 0;
        //Serial.println("vermelho");
  } else {
    vermelho = 255, verde = 255, azul = 255;
   // Serial.println("verde");
  }
}
/////////////////////////////////////////////////////////////////////////////////////////
void contaTempo(int _tempo) {
  static unsigned long lastTime1 = 0;
  unsigned long currentTime = millis();  // guarda o tempo atual

  if ((currentTime - lastTime1) >= 1) {
    lastTime1 = currentTime;
    tempo++;
  }
}

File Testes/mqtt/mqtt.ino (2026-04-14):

//////////////////////////////////////////////////////////////////////////////////////////////////////////////
//             Pulsadores Tactil com Internet das Coisas: ESP32, IBM Watson e Node-Red com ESP32 Dev module
//                              Modulo master
//   build 08/09/2021 by Eng. Raul 
//  v2.0
//////////////////////////////////////////////////////////////////////////////////////////////////////////////

//============================================================================================================= */
// Link da pagina de controle:
//https://internetofthings.ibmcloud.com/
//https://autorobotica.mybluemix.net/ui/#!/0?socketid=UcajIY2IPIzD0mtiAADT
// Link NODERED
//https://autorobotica.mybluemix.net/red/#flow/544e9c75.42d854

//============================================================================================================= */
//Referencias:
//https://www.youtube.com/watch?v=9bN3aXjRbF4&ab_channel=FernandoKTecnologia
//https://www.youtube.com/watch?v=9ExcHytl4mg&t=672s&ab_channel=FernandoKTecnologia
//https://www.youtube.com/watch?v=cuSimO5e_fU&ab_channel=FernandoKTecnologia
//https://www.youtube.com/watch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
//https://www.youtube.com/watch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


// =============================================================================================================
// --- Bibliotecas Auxiliares ---
//https://flows.nodered.org/node/node-red-contrib-scx-ibmiotapp
//https://github.com/zhouhan0126/DNSServer---esp32
//https://github.com/zhouhan0126/WebServer-esp32
//https://github.com/zhouhan0126/WIFIMANAGER-ESP32

#include <Arduino.h>
#include <WiFi.h> 
#include <PubSubClient.h>
#include <ArduinoJson.h>
#include <DNSServer.h>
#include <WebServer.h>
#include <WiFiManager.h>
#include "BluetoothSerial.h"

// =============================================================================================================
// --- Variáveis Globais para conecção bluetooth---

String MACadd = "4C:EB:D6:74:C9:0A";// "A4:E5:7C:47:10:CA" "4C:EB:D6:74:C9:0A"Endereço do Bluetooth
uint8_t address[6] = {0x4C, 0xEB, 0xD6, 0x74, 0xC9, 0x0A};// {0xA4, 0xE5, 0x7C, 0x47, 0x10, 0xCA};{0x4C, 0xEB, 0xD6, 0x74, 0xC9, 0x0A}
String name = "Pulsador";
char *pin = "1234"; //<- standard pin would be provided by default
bool connected;

// =============================================================================================================
// --- Variáveis Globais para conecção com o IBM Ilot ---
//---//https://internetofthings.ibmcloud.com/
// Altere estes dados pelos obtidos ao cadastrar o novo dispopsitivo no IBM Watson Iot

const String ORG = "xo3jx7"; //ID  da organização no IBM Watson
const String DEVICE_TYPE = "ESP32";
const String DEVICE_ID = "PULSADOR"; //ID DO DISPOSITIVO
#define DEVICE_TOKEN "0123456789"

// =============================================================================================================
// DEFINIÇÕES DE PINOS
#define vibrador 17
#define led 16
#define ledOnBord 02 //led para mostrar conexão
#define botaoDesliga 15
#define botaoLiga GPIO_NUM_4
// =============================================================================================================
// FORMADO DAS MENSAGENS PARA MQTT

const char eventTopic[] = "iot-2/evt/status/fmt/json";
const String CLIENT_ID = "d:" + ORG + ":" + DEVICE_TYPE + ":" + DEVICE_ID; //Constantes para conexão do servidor mqtt
const String MQTT_SERVER = ORG + ".messaging.internetofthings.ibmcloud.com";

#define COMMAND_TOPIC_R1 "iot-2/cmd/commandR1/fmt/json"
#define COMMAND_TOPIC_R2 "iot-2/cmd/commandR2/fmt/json"
#define COMMAND_TOPIC_R3 "iot-2/cmd/commandR3/fmt/json"
#define COMMAND_TOPIC_R4 "iot-2/cmd/commandR4/fmt/json"
#define COMMAND_TOPIC_R5 "iot-2/cmd/commandR5/fmt/json"

// =============================================================================================================
// variáveis globais

int cont = 0;
int liga;
int alterna;
long intensidade = 100;
int duracao;
int inicia;
const int ledPin = 05;
String comando = "";
char valorRecebido;
bool comectado;

//int botaoDesliga = 15; //pino para dormir

// =============================================================================================================
// objetos para conexão do servidor mqtt


BluetoothSerial SerialBT;
hw_timer_t * timer = NULL;

void Desliga(){
    liga = 0;
    Serial.println("Desligando");
    SerialBT.write('d');
    digitalWrite(ledOnBord, LOW);
    digitalWrite(vibrador, LOW);
    digitalWrite(led, LOW);
    timerEnd(timer);
    timer = NULL; 
    esp_deep_sleep_start();
    
}

void cb_timer(){
  static bool estado = 0;
  if(digitalRead(botaoDesliga)==0)  Desliga();
  if (estado == LOW) {
    digitalWrite(led, estado);
    estado = HIGH;
  }
  else {
    digitalWrite(led, estado);
    estado = LOW;
  }
      
      
    static unsigned int counter = 1;
    /* Serial.println("cb_timer(): ");
    Serial.print(counter);
    Serial.print(": ");
    Serial.print(millis()/1000);
    Serial.println(" segundos"); */
    if(comectado) digitalWrite(led, HIGH);
    else  digitalWrite(led, estado);
    // if the led is off turn it on and vice-versa:
      
    // set the led with the estado of the variable:
    digitalWrite(ledOnBord, estado);

}

void startTimer(){
  
    //inicialização do timer. Parametros:
    /* 0 - seleção do timer a ser usado, de 0 a 3.
      80 - prescaler. O clock principal do ESP32 é 80MHz. Dividimos por 80 para ter 1us por tick.
    true - true para contador progressivo, false para regressivo
    */
    timer = timerBegin(0, 80, true);

    /*conecta à interrupção do timer
     - timer é a instância do hw_timer
     - endereço da função a ser chamada pelo timer
     - edge=true gera uma interrupção
    */
    timerAttachInterrupt(timer, &cb_timer, true);

    /* - o timer instanciado no inicio
       - o valor em us para 1s
       - auto-reload. true para repetir o alarme
    */
    timerAlarmWrite(timer, 1000000, true); 

    //ativa o alarme
    timerAlarmEnable(timer);
    
}

// =============================================================================================================
// CONFIGURAÇÃO
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
